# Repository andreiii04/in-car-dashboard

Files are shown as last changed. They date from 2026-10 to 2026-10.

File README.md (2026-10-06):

# In-Car Dashboard

A standalone telemetry display for a car: a custom 4-layer STM32 board with a 2.8" TFT, a 6-axis IMU, an environmental sensor and a GPS module. It powers from the car's 12 V socket through an ordinary USB-C car charger, starts a fresh session on every power-on with no buttons, shows live driving numbers, and writes a summary of each drive to an SD card.

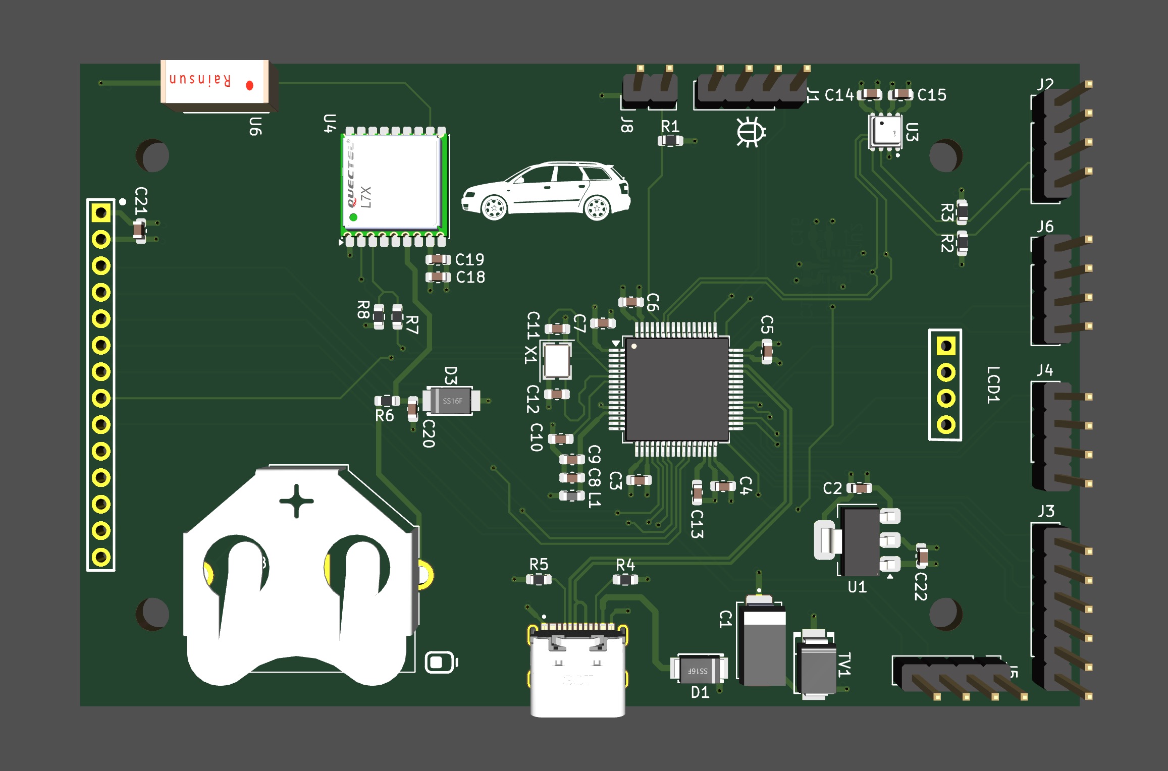
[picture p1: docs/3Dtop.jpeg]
Board, 3D view from the top


## What it shows and records

**Live, on the screen**
- A G-meter: a dot for the acceleration you feel, its magnitude, and the session's hardest braking, acceleration and cornering each way around the ring
- Speed, session maximum and distance (GPS)
- Temperature, humidity, pressure and gas resistance (BME680)
- Local time, time since power-up, satellites, position and altitude (GPS fused with the barometer)

**Per drive, on the SD card** — one file, `SESSIONS.JSON`, a single valid JSON document with one fixed-size block per drive:
- Start time (UTC and local), duration, moving time, distance, top speed
- Hardest acceleration, braking and cornering, worst lateral load against the car's rollover limit
- Peak pitch and roll and how close they came to the car's limits
- Temperature, pressure and humidity min/max/average; climb and descent
- A `faults` section with every init result and error counter, so a drive that went wrong says so in its own record

The record is rewritten in place every 10 s, because the car cuts power without warning. A cut can only ever damage the current drive's block, and the two writes that move the closing bracket are ordered so an interrupted one repairs itself on the next boot.

## Hardware

| Part | Role | Interface |
|---|---|---|
| STMicroelectronics STM32F446RCT6 | Cortex-M4F MCU, 180 MHz, 256 KB flash, 128 KB RAM | — |
| STMicroelectronics LSM6DSOTR | 6-axis accelerometer + gyroscope | I2C1, data-ready on INT1 |
| Bosch Sensortec BME680 | Temperature, pressure, humidity, gas | I2C1 |
| Quectel L76L-M33 | GPS + GLONASS receiver, 1 Hz NMEA | USART1, 9600 baud |
| GPS ANT-1 chip antenna | Passive GNSS antenna | RF_IN |
| KMRTM28028-SPI / MSP2807 | 2.8" 320×240 TFT, ILI9341 driver, full-size SD socket | SPI1 (display), SPI2 (SD) |
| Microchip MCP1825ST-3302E | 3.3 V LDO | — |
| GCT USB4930-00-A | USB-C: power, and a USB CDC debug console | USB OTG FS |
| Keystone 3003 | Coin-cell holder for the GPS backup supply | V_BCKP |

Protection on the 5 V input: a series Schottky against reverse polarity, a TVS diode and a 220 µF tantalum bulk capacitor. Five expansion headers (I2C, SPI3/I2S3, USART6, CAN1, two 32-bit timer channels) carry the protected 5 V rail for future add-on boards. Flashing and debugging go through a 4-pin SWD header with an ST-Link.

- **PCB:** 4-layer FR4, 1.6 mm, ENIG (two LGA sensors), 61.6 × 95.79 mm. Solid ground on In1, 3.3 V pour on In2. Made at JLCPCB.
- **Schematic:** three sheets, pictured below, or open the KiCad project.
- **Parts list:** [`docs/bom.csv`](docs/bom.csv), with manufacturer part numbers.

<p>
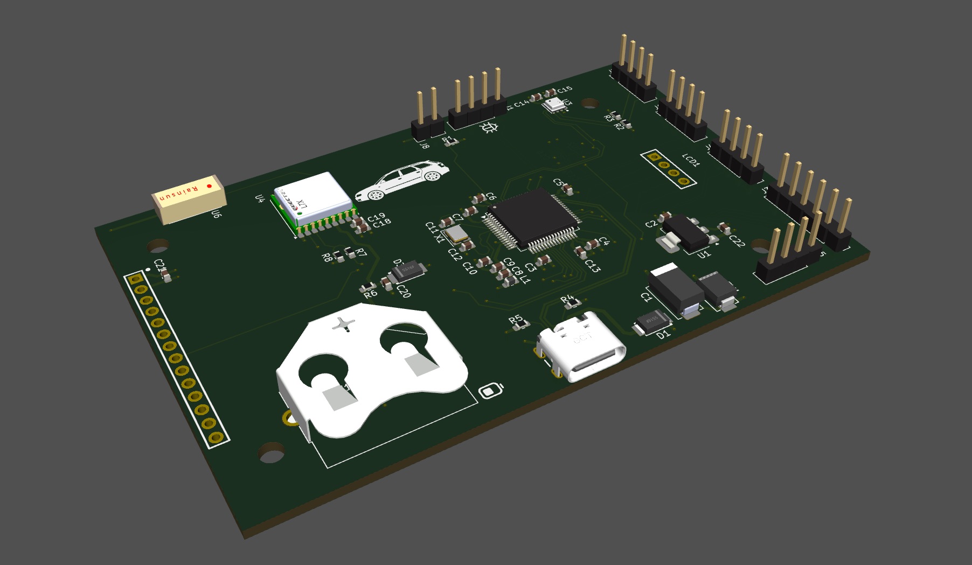
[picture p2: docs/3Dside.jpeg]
Board, side view
  
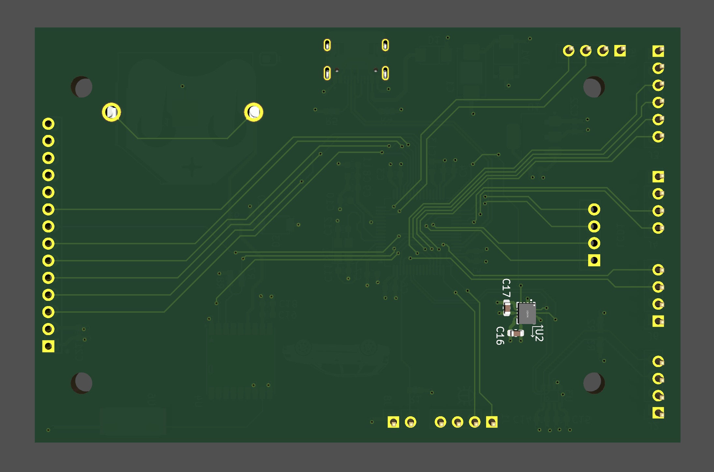
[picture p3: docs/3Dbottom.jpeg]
Board, bottom view, with the IMU on the underside
  
</p>

**Display mounting.** The display module is not soldered to the board and does not appear in the renders: female 2.54 mm sockets are soldered into all 18 LCD1 positions (the 14-pin display and touch row and the 4-pin SD row), and male headers on the module's own PCB plug into them, so the screen stacks face-up on top of the main board and can be lifted off. The board's four M3 holes match the module's 44 × 76.08 mm hole pattern, for standoffs between the two.

### Case

A 3D-printed bottom tray holds the board by its walls, with the USB-C opening on one side, intake vents at the BME680 end and exhaust vents at the far end. Source: [`hardware/case/bottom_tray.FCStd`](hardware/case/bottom_tray.FCStd) (FreeCAD 1.1), described in [`docs/dash_case.md`](docs/dash_case.md). The top case with the display bezel and SD slot is not designed yet.

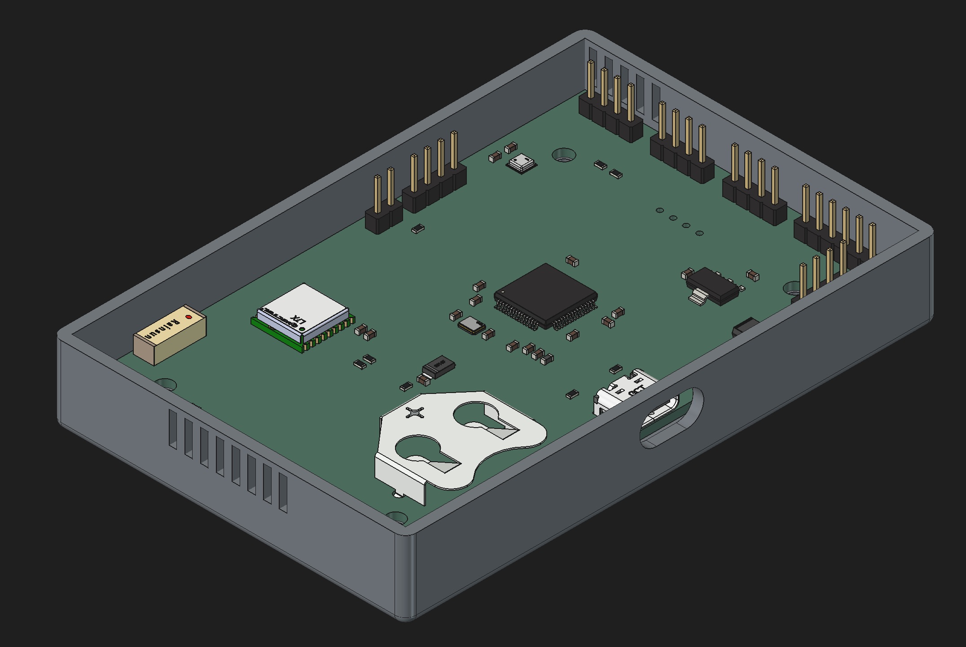
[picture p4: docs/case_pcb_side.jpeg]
Board in the bottom tray


### Schematic and layout

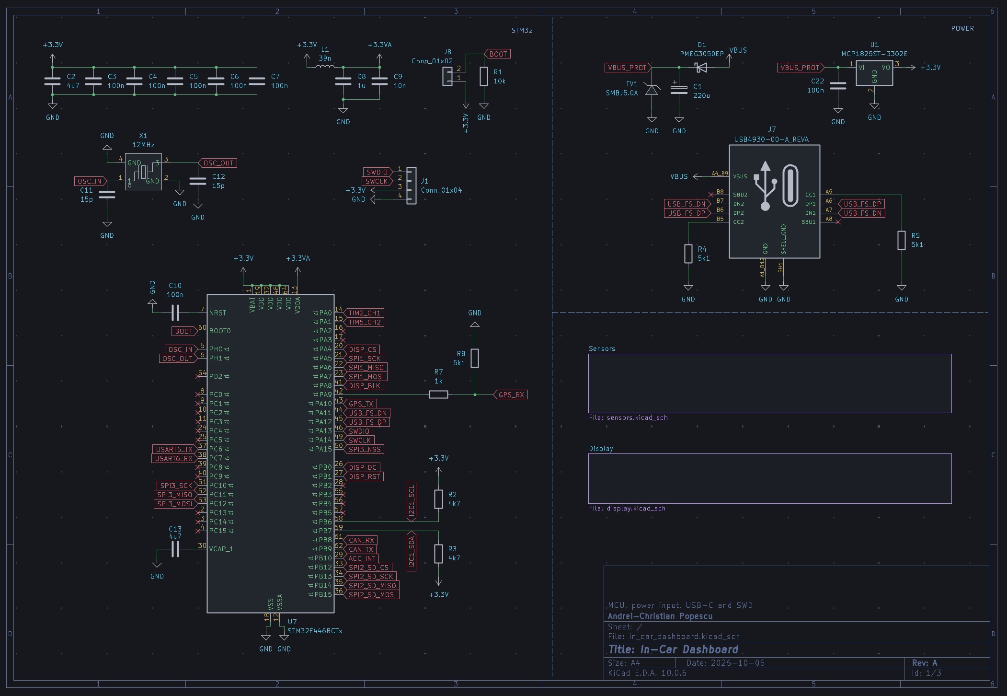
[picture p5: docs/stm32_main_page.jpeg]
Schematic sheet 1: MCU, power input, USB-C and SWD


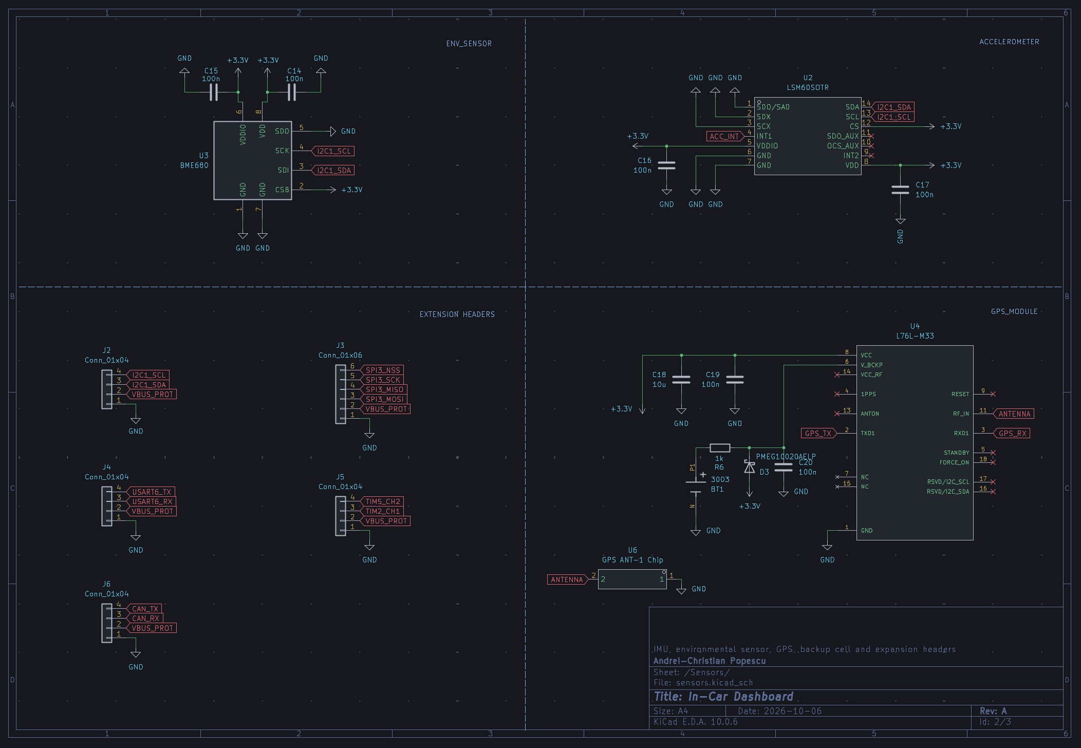
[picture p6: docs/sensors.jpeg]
Schematic sheet 2: IMU, environmental sensor, GPS, backup cell and expansion headers


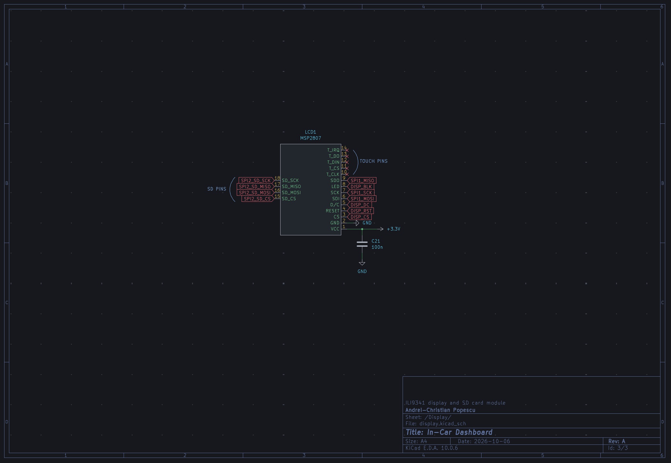
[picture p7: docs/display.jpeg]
Schematic sheet 3: display and SD card module


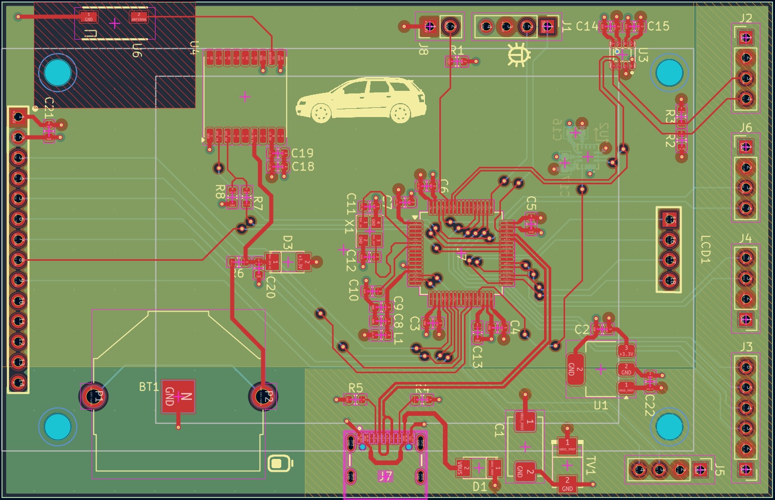
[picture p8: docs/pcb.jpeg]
PCB layout, top view


### Known issues on this revision

- **No copper keepout under the GPS antenna.** The antenna's datasheet asks for a copper-free corner on all layers; it was missed. With solid copper underneath, the module heard nothing, so the chip antenna is lifted about 1 cm above its pads on two wire stubs; it fixes with 9–16 satellites that way. A rev B would add the keepout or a U.FL connector for a patch antenna.
- **The display module never drives its SDO line,** so register reads return `0xFF`. The firmware treats the ID check as advisory; writes work normally.
- **The IMU sits on the underside of the board,** so the firmware's axis map flips two axes. This is by design, but it surprises anyone reading raw values.

## Firmware

C, bare-metal superloop on STM32 HAL (CubeMX-generated init), built with CMake and arm-none-eabi-gcc. No RTOS yet.

The loop is paced by the IMU's own data-ready interrupt at about 105 Hz. Each sample is mapped from sensor axes to vehicle axes (ISO 8855: X forward, Y left, Z up), run through the attitude filter, then handed to the trip statistics. Around that, on every pass:
- the GPS ring buffer is drained and NMEA sentences parsed
- the BME680 is triggered and read back in two halves every 3 s, so nothing blocks
- the screen redraws at 20 Hz, one 16-line band per pass, with no framebuffer
- the session record is rewritten every 10 s

| Stack | Modules |
|---|---|
| Sensors | `i2c_bus` → vendor drivers (ST `lsm6dso`, Bosch `BME68x`) → platform glue → `imu`, `env` |
| GPS | `uart_bus` (interrupt-driven ring buffer) → `nmea` (parser) → `gps` |
| Fusion and statistics | `attitude` (complementary filter, full Euler kinematics, mount rotation), `trip` (distance, peaks, lean, rollover margins, GPS-dropout coasting), `elevation` (GPS altitude fused with barometric pressure) |
| Display | `lcd` (ILI9341 over SPI) → `gfx` (band renderer, dirty rectangles) → `screen` |
| Storage | `sd_spi` (SD SPI mode, CRC on every command and block) → FatFs → `session_record` → `session_log` |
| Console | `usb_serial` (printf over USB CDC) → `console` |

Everything with no hardware in it is host-testable and tested on a PC, 243 checks across seven modules: `nmea`, `attitude`, `trip`, `elevation`, `gfx`, `sd_crc`, `session_record`. Expected values come from independent derivations rather than restatements of the code under test. Car- and mount-specific constants (axis map, calibration, wheelbase, track, centre-of-gravity height) live in one header, `firmware/App/Inc/vehicle_axes.h`, explained in [`docs/vehicle_info.md`](docs/vehicle_info.md).

Some decisions worth knowing before changing anything:
- **Pitch and roll come from accelerometer and gyroscope fused.** The car's own acceleration is subtracted first, using GPS speed and speed × yaw rate, so braking and cornering don't read as tilt.
- **GPS speed below 10 km/h is treated as standing still.** A poor fix wanders by several km/h at rest, so the floor is applied once, where the fix enters the trip statistics.
- **Climb and descent come from the barometer alone.** The GPS height after a cold start drifts by up to hundreds of metres over minutes, and counting that as climb was a real bug.
- **The mount is calibrated in the car,** with the board's rest reading measured in both directions on the same spot and averaged, so a sloping parking space cancels out.

The reasoning behind these and most other choices, written down while I learned embedded from scratch, is in [`docs/notes.md`](docs/notes.md); code comments that say "see docs/notes.md" point there.

## Repository layout

```
firmware/            STM32 firmware (CMake, CubeMX project dashboard_firmware.ioc)
  App/               hand-written code: Inc/, Src/, Drivers/ (vendor), Fonts/ (generated)
  Core/ Drivers/ FATFS/ Middlewares/ USB_DEVICE/   CubeMX- and ST-generated
  tests/             host tests, each file carries its own compile line
  tools/             font generator
hardware/
  pcb/               KiCad 10 project in_car_dashboard
  libraries/         custom symbols, footprints and 3D models used by the board
  case/              FreeCAD source of the case tray
docs/                case design note, the car's numbers and what each one is used for, my notes
                     from building it, schematic and board pictures, renders, BOM
```

## Building and flashing

Requirements: CMake ≥ 3.22, Ninja, and `arm-none-eabi-gcc` on the `PATH` (STM32CubeCLT provides all three).

```sh
cd firmware
cmake --preset Debug
cmake --build build/Debug
```

The output is `build/Debug/dashboard_firmware.elf`. Flash it over SWD with an ST-Link: from an IDE (CLion with the STM32 plugin, or STM32CubeIDE), or with STM32CubeProgrammer. The serial console is the USB-C port itself, at `/dev/cu.usbmodem*` on macOS; the baud rate is ignored.

Host tests build with any C11 compiler. For example:

```sh
cd firmware
cc -std=c11 -Wall -Wextra -I App/Inc tests/test_trip.c App/Src/trip.c -lm -o /tmp/test_trip && /tmp/test_trip
```

Each file in `tests/` has its own line in its header.

## Opening the hardware

- **PCB:** open `hardware/pcb/in_car_dashboard.kicad_pro` in KiCad 10. The project's symbol and footprint paths are relative to the project, so the custom parts in `hardware/libraries/` resolve on any machine; everything else comes from KiCad's standard libraries. The 3D models of the custom parts are not included, since they come from third parties: the board opens, checks and exports normally, and those parts just show without a body in the 3D viewer. To get them back, download the STEP models from the manufacturers and put each in `hardware/libraries/<library>/<library>.3dshapes/` under the file name its footprint asks for.
- **Case:** open `hardware/case/bottom_tray.FCStd` in FreeCAD 1.1. It was printed in one piece, floor down, no supports.

## Datasheets

Not included in the repository; all are available from the manufacturers:
- STM32F446RC (STMicroelectronics)
- LSM6DSO (STMicroelectronics)
- BME680 (Bosch Sensortec)
- L76L-M33 datasheet and its GNSS protocol specification (Quectel)
- ILI9341 (Ilitek)
- MSP2807 / KMRTM28028-SPI module drawing
- MCP1825 (Microchip)
- USB4930 / USB4940 (GCT)
- 3003 coin-cell holder (Keystone)
- PMEG10020AELP and PMEG3050EP Schottky diodes (Nexperia)
- SMBJ5.0A TVS diode (SMBJ series)
- GPS ANT-1 chip antenna
- SD Physical Layer Simplified Specification v2.00 (SD Association)

## Status

Working on the bench and in the car. Bring-up is complete: console, sensors, calibration, GPS, attitude, interrupt-paced sampling, display, SD logging and the main loop. The first long drive, 118.5 km, matched the route distance and ran with every fault counter at zero.

Still to do:
- Air-quality index through Bosch's BSEC library, which is closed source and won't be in this repository
- Tuning the filters against logged drives, and a faster GPS rate
- The top case
- A second screen for pitch and roll off-road

## License

The hardware design, case, firmware and documentation in this repository are released under the [MIT License](LICENSE).

The custom symbols and footprints in `hardware/libraries/` were drawn from, or adapted from, manufacturer and EasyEDA / SnapEDA sources; their 3D models are not redistributed here.

Third-party code keeps its own licence:
- **CMSIS:** Apache 2.0, see `firmware/Drivers/CMSIS/LICENSE.txt`
- **STM32F4 HAL:** BSD-3-Clause, see `firmware/Drivers/STM32F4xx_HAL_Driver/LICENSE.txt`
- **STM32 USB Device Library:** ST SLA0044, see `firmware/Middlewares/ST/STM32_USB_Device_Library/LICENSE.txt`
- **FatFs R0.12c:** ChaN's FatFs licence, in its source header
- **Bosch BME68x SensorAPI:** BSD-3-Clause
- **ST LSM6DSO driver:** BSD-3-Clause, from ST's `lsm6dso-pid` repository

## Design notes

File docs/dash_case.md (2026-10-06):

# Car Dashboard — Bottom Case Tray (FreeCAD 1.1.3, macOS)

Status: **bottom tray printed and test-fitted (Oct 2026).** The board drops
in and is held snugly by the walls alone, sits flat, and the USB-C cable seats.
Not yet screwed down; on the car's dash since 4 Oct 2026, front edge forward,
~43° nose up. Final object: `Fillet001`. Next up: standoffs, then design the
top case.

**Files** (in `hardware/case/`): `bottom_tray.FCStd` is the FreeCAD source;
`bottom_tray.3mf` and `bottom_tray.stl` are the meshes exported from it per
section 8. Inside the FreeCAD file the imported board is still called
`IN_CAR_DASHBOARD 1` — the KiCad project's old name.

---

## 1. Context

Enclosure for the STM32F446RCT6 in-car telemetry dashboard PCB. This note
covers the **bottom tray only** — the part the PCB bolts into. The top case
(display bezel + SD-card access) comes later.

Everything is modelled in the **Part** workbench with primitives and booleans
— no Sketcher, no constraints. Every feature is a Cube or Cylinder with typed
Placement values. The geometry is all rectangular/cylindrical, so this keeps
every dimension explicit and easy to trace back to a number in this file.

---

## 2. Coordinate system

The KiCad STEP export (`IN_CAR_DASHBOARD 1`) is placed so the board's
bottom-left corner sits on the origin. **All case geometry is dimensioned in
the PCB's own frame — never move the STEP.**

| Reference | Value |
|---|---|
| Board outline | 61.60 (X) × 95.80 (Y) |
| Board occupies | X: 0 → +61.60, Y: 0 → −95.80 |
| Board bottom face | z = 0 |
| Board top face | z = +1.52 |
| Deepest bottom-side protrusion | z = −1.00 (clipped THT pin tips) |

Wall naming used below: **X = 0 / X = 61.6** are the long walls, **Y = 0**
(BME680 end) and **Y = −95.8** (coin-cell end) are the short walls.

The Top view renders rotated 90° (+X up-screen, +Y left), so the board looks
landscape even though it's portrait.

---

## 3. Vertical stack

All z values are in the PCB frame, so board thickness is already included.

| Feature | z |
|---|---|
| Floor underside | −6.00 |
| Cavity floor / boss base | −4.00 |
| Boss top / board underside | 0.00 |
| Board top face | +1.52 |
| Wall top | **+9.00** (7.48 above the board top) |
| Display PCB underside (10 mm standoff) | ≈ +11.52 |

- Floor 2.0 mm, walls 2.0 mm, inside wall height 13.0 mm
- Bosses 4.0 mm tall → 3.0 mm clearance under the clipped pin tips
- 2.5 mm gap between the wall top and the display PCB
- External envelope: **67.60 × 101.80 × 15.00 mm**
- Edges broken for handling: 2.0 mm fillet on the 4 vertical corners, 0.8 mm
  on the 4 bottom edges. Top edges left sharp — the top case mates there.

---

## 4. Mounting

Ø3.20 PCB holes (M3 clearance). The pattern matches the MSP2807 display
exactly: **44.00 × 76.08**, X-centred at (61.6 − 44)/2 = 8.80.

| | X | Y |
|---|---|---|
| H1 | 8.80 | −12.80 |
| H2 | 52.80 | −12.80 |
| H3 | 8.80 | −88.88 |
| H4 | 52.80 | −88.88 |

Y values were probed directly off the STEP (hole edges at 12 and 6 o'clock,
averaged) and cross-checked against the datasheet's 76.08 span and 6.92
bottom offset.

Bosses are Ø6.5, with a Ø2.5 pilot through boss + floor. That gives 6 mm of
thread engagement for the standoff stud.

**Fastening stack:**
- **Board → tray:** M3 male–female hex standoff. The 6 mm male stud
  thread-forms into the boss pilot and the standoff shoulder clamps the board.
- **Display → standoff:** M3×6 pan head from above, into the standoff's
  female end.
- Standoff body ~10 mm (10+6 variant); still to be confirmed against the
  MSP2807's back-side clearance.
- Hand-tighten only. Thread-formed plastic tolerates about 3–4 insertion
  cycles.

---

## 5. USB-C cutout

**Connector:** GCT USB4930-00-A (the STEP model is `usb4930_00_a`). The
supplier's drawing link points to the USB4940 — the measured model height
matches the USB4940 drawing.

- Mouth flush with the board edge at X = 61.6
- Centre measured at **Y = −48.10, z = 3.25**
- Shell top at z ≈ 4.9

**Why the hole is stepped.** The mouth sits 3.0 mm behind the outer wall face
(1 mm gap + 2 mm wall). The datasheet only guarantees ≥ 1.85 mm between the
receptacle face and the plug body when fully mated, so the cable's
plug body (the moulded part) has to enter the wall by ~1.2 mm. A hole sized
for the receptacle alone would stop the plug short of full insertion. A
pure funnel fails the same way — it narrows faster than the plug body needs.

The solution is a counterbore for the plug body, a smaller through-hole for
the metal plug, and a small lead-in chamfer between them. All three are
stadium shapes (straight sides, round ends), concentric on the receptacle.

| Feature | Size | X range | z range |
|---|---|---|---|
| Pocket (plug body) | 12.50 × 6.75, r 3.375 | 63.2 → 64.6 (1.4 deep) | −0.125 → 6.625 |
| Through-hole (metal plug) | 9.80 × 4.00, r 2.0 | 62.6 → 63.2 | 1.25 → 5.25 |
| Lead-in chamfer | 0.5 mm equal distance | through-hole rim at X = 63.2 | — |

- 2.375 mm of wall above the pocket, 3.75 mm above the through-hole
- 0.6 mm web between the pocket floor and the inner wall face
- The pocket is sized tight for a slim plug body. The USB-C spec maximum is
  12.35 × 6.5, so bulky plugs may not fit; if one is tight, grow the pocket
  radius by +0.15 mm.

---

## 6. Ventilation

The BME680 sits at **(6.55, −18.65)** on the top side, close to the Y = 0 /
X = 0 corner. Vents are placed so fresh air reaches the sensor first and
leaves at the far end, away from the MCU and regulator heat.

All slots are **1.5 wide × 6.0 tall**, through the 2 mm wall, **z 2.0 → 8.0**
(1.0 mm of wall left above them), with a **3.0 mm pitch**.

| Wall | Role | Slots | Slot X centres |
|---|---|---|---|
| Y = 0 (BME end) | inlet | 5 | 0.55 / 3.55 / **6.55** / 9.55 / 12.55 — centred on the BME680 |
| Y = −95.8 (far end) | exhaust | 8 | 20.3 → 41.3 — centred on the board (30.8) |

I didn't put vents on the long X = 0 wall, to keep dust down. The Y = 0 end
will face the car's climate vents. Keep in mind that a direct air jet on the
inlet will bias the BME680 toward vent-air temperature and humidity rather
than cabin air.

---

## 7. Feature tree

```
Fillet001                       ← FINAL — 0.8 mm on the 4 bottom edges
└─ Fillet                       ← 2.0 mm on the 4 vertical corners
   └─ Chamfer                   ← 0.5 mm lead-in on USB through-hole
      └─ Cut002  (Refine = true)      ← tray minus all cutouts
         ├─ Cut001                 ← base tray with boss pilots
         │  ├─ Fusion               ← shell + bosses
         │  │  ├─ Cut
         │  │  │  ├─ Cube           outer   67.6 × 101.8 × 15.0  @ (−3, −98.8, −6)
         │  │  │  └─ Cube001        cavity  63.6 × 97.8  × 13.5  @ (−1, −96.8, −4)
         │  │  └─ Cylinder…003      bosses  r 3.25, h 4   @ holes, z −4
         │  └─ Fusion001            pilots  r 1.25, h 9   @ holes, z −7
         └─ Fusion002               ← all cutting tools
            ├─ Cube002              pocket middle   2 × 5.75 × 6.75   @ (63.2, −50.975, −0.125)
            ├─ Cylinder008/009      pocket ends     r 3.375, h 2      @ y −50.975 / −45.225, z 3.25
            ├─ Cube003              through middle  1.9 × 5.8 × 4     @ (62.1, −51.0, 1.25)
            ├─ Cylinder010/011      through ends    r 2.0, h 1.9      @ y −51.0 / −45.2, z 3.25
            ├─ Cube004…008          vent A  1.5 × 3 × 6  @ x −0.2…11.8,  y 0.5,   z 2
            └─ Cube009…016          vent C  1.5 × 3 × 6  @ x 19.55…40.55, y −99.3, z 2
```

The vertical corners and the bottom edges ended up as two separate Fillet
operations rather than one, because pressing Enter in the radius box closes
the dialog instead of just committing the value. Same result, one extra node.

USB cylinders are rotated Axis (0, 1, 0), Angle 90°, so they run along +X.

**Modelling rules I stuck to:**
- Every cutting tool overshoots the faces it cuts. Coplanar faces break
  booleans — that's also why the cavity cube pokes 0.5 mm above the wall top.
- The chamfer and the two fillets are the **last** operations, in that order.
  They're bound to edge IDs (the chamfer to Edge193/196/199/202 of `Cut002`),
  so any upstream change can renumber them and break the chain. If that
  happens, delete them and redo only those three steps.
- Bottom fillets stay small. A fillet on a bottom edge is a real overhang
  against the build plate, so anything much past 0.8 mm droops on the first
  layers. The vertical corner fillets cost nothing — that surface stays
  vertical all the way up.

---

## 8. Printing

**Export:**
1. `Fillet001` → Part → Check Geometry. Must report no errors.
2. Hide `IN_CAR_DASHBOARD 1` (select, Space).
3. Mesh Design workbench → select `Fillet001` → Meshes → Create mesh from
   shape → **Standard**, surface deviation `0.01 mm`, angular deviation `5°`.
   The fine deviation matters: the USB hole ends and the corner fillets come
   out visibly faceted at the default.
4. Select the **mesh** object → File → Export → **3MF** (preferred) or STL.
5. Also export `Fillet001` itself as **STEP** from the Part workbench, as the
   editable version to hand over alongside the mesh.

3MF stores units explicitly; STL is unitless and is occasionally read as
inches, so say "mm" when handing it over.

**Print setup:**
- Orientation: floor on the bed, walls up
- No supports — the slot tops and USB openings are short bridges (≤ 5.8 mm),
  and the round ends are self-supporting
- 0.4 nozzle, 0.2 mm layers
- ≥ 4 perimeters and ≥ 30 % infill, so the bosses are close to solid
  around the pilot holes (the standoffs thread-form into them)
- Material: PLA is fine for the fit test. For the car, use **PETG or ASA** —
  PLA starts softening around 55–60 °C, which a parked car easily exceeds.

**After the first print, check:**
- [x] USB-C cable seats fully
- [ ] Standoffs thread in without cracking the bosses — no screws fitted yet
- [x] Board sits flat with the USB mouth centred in the hole — the fit is
  tight enough to hold the board without screws, and the tray sits flat on
  the table

**First fit result (3 Oct 2026):** the board was re-calibrated in the tray, on
the same table as the original bench calibration, and those values are now the
"flat" set in `vehicle_axes.h`. The bench values were off by pitch +0.9° /
roll −1.3° because the bare board had rested on its THT solder tails, not on
its mounting holes; the tray is the better flat reference. Since 4 Oct the
tray sits on the dash and the active set is the car calibration (43.4° nose
up, 2.5° roll), described in [`vehicle_info.md`](vehicle_info.md).

---

## 9. Open items

- **Top case:** needs a cutout at the board edge for the **full-size SD card**
  (measured ~9.5 mm above the board top including board thickness), so the
  card stays removable without opening the case. It mates on the wall top at
  z = 9.0.
- **Standoff length:** confirm the 10 mm body against the MSP2807's back-side
  components before ordering.
- **Boss heights:** confirm all four read `Height = 4`, `z = −4`. Earlier, one
  looked prouder in an isometric view. Still unchecked: a proud boss tilts the
  board, and the in-tray calibration would bake that tilt in as "flat", so it
  cannot reveal one. Measure the heights once the standoffs clamp the board.

---

## 10. Reference files

- MSP2807 mechanical drawing — display PCB 50 × 86, hole pattern 44 × 76.08,
  4 × Ø3.20
- GCT USB4930 specification and USB4940 drawing — receptacle and mating depth
- BME680 datasheet — sensor position and venting

The datasheets are not in the repository; the README lists them. The board
itself is `hardware/pcb/in_car_dashboard.kicad_pcb` (KiCad STEP export).

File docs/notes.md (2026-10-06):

# notes

my own notes while learning this. plain language on purpose, i rewrite bits as i
understand them better.

two words that come up a lot:

  step      the bring-up order i followed, one piece of the board at a time
              0  usb console         5  loop paced by the IMU's data-ready line
              1  i2c sensors         6  display
              2  bench calibration   7  sd card
              3  gps                 8  the main loop
              4  pitch and roll      9  BSEC, 10 tuning - not done yet
  session   one power-on, one record in SESSIONS.JSON on the card
              5      19 sep         first drive, 18 min
              6-8    28 sep-3 oct   back on the bench with the fixes from 5
              17     3 oct          first long drive, 2 h 19 min, 118.5 km

## the layers

the code is stacked - each layer only talks to the one under it. the file list
and what each layer does is in the README; what matters here is why.

swap the IMU for a different chip and only imu.c and its glue file change,
everything above keeps working. it also keeps each file small enough to read in
one go.

three files sit above all of it and are stacked on nothing - attitude.c, trip.c
and elevation.c get handed plain numbers by main. nothing hardware-shaped goes
in, so all three run on the mac.

the usb console is the one stack that is mostly ST's:

  usb_serial.c             my module - printf lands here
  usbd_cdc_if.c            ST's "serial port" class
  usbd_core.c              ST's core - runs the usb interview
  usbd_conf.c              ST's glue down to the HAL
  HAL                      the usb hardware on PA11 and PA12

vendor drivers i re-download rather than patch by hand - the next download would
wipe the patch and i would not notice.

## what a driver actually is

a chip like the LSM6DSO is a box of numbered mailboxes called registers, one
byte each. write to 0x10 and the sample rate changes; read 0x28 to 0x2D and you
get the accelerometer. that is the whole interface.

a driver is code that knows which mailbox is which, so i don't memorise 100
numbers. instead of "put 0x40 into register 0x10" i write

  lsm6dso_xl_data_rate_set(..., LSM6DSO_XL_ODR_104Hz)

ST and Bosch publish these free, written to work on any microcontroller. which
is why the glue file exists.

## why the glue file exists

ST's driver has no idea what an STM32 is. it asks me for two functions instead -
one that reads bytes, one that writes them - and calls those when it needs the
bus.

handing over a function like that is a function pointer: a variable holding
where a function lives instead of a number.

so lsm6dso_platform.c has two small functions in the shape ST asked for, each
calling my i2c_bus_read_reg / i2c_bus_write_reg, bundled into a struct:

  stmdev_ctx_t lsm6dso_ctx = {
      .write_reg = lsm6dso_platform_write,
      .read_reg  = lsm6dso_platform_read,
      .mdelay    = lsm6dso_platform_delay,
      .handle    = &lsm6dso_i2c_addr,
  };

that struct is the context, and every ST call takes it first.

.handle is a spare pointer ST hands back untouched. i point it at the device
address, because my i2c_bus functions need to know which chip to talk to and
ST's driver has no other way of telling me. Bosch does the same and calls it
intf_ptr.

## I2C, enough to follow the code

two wires shared by every chip - SDA is data, SCL is clock. each chip has an
address so they don't talk over each other. BME680 is 0x76, LSM6DSO is 0x6A.

addresses are 7 bits. the HAL wants them shifted left by one because it uses the
freed bottom bit for read vs write. my wrapper does the shift inside, so i
always pass the plain datasheet number.

a normal read is "hey 0x6A, i want register 0x28" then "give me 6 bytes".
HAL_I2C_Mem_Read does that whole exchange in one call, which is why i used it
instead of building the sequence myself.

## what an IMU is

inertial measurement unit. one package holding:

  accelerometer   how hard it is being pushed
  gyroscope       how fast it is being turned

3 axes each, 6 numbers - hence 6-axis.

i named my module imu_ and not lsm6dso_ because ST's driver owns that prefix.
lsm6dso_status_t already exists in their header, so reusing it would not compile.
imu also names the job instead of the part.

## accelerometer numbers

measured in g, one g being earth's gravity.

the confusing bit: sitting still on a table it does not read zero. it reads 1 g
on whichever axis points up, because gravity is always being measured. that is
what makes tilt possible.

rough car numbers:

  sitting still            1 g on the vertical axis
  hard braking             about 1 g forwards
  emergency stop           up to 1.2 g
  normal cornering         0.3 to 0.8 g sideways
  pothole                  2 to 3 g extra straight up, very briefly

## gyroscope numbers

dps, degrees per second.

  90 dps    quarter turn every second
  360 dps   full spin every second

a bend at 50 km/h on a 30 m radius is about 26 dps. a tight hairpin taken slowly
is about 48 dps. normal driving basically never passes 60 dps.

## ODR - output data rate

how many measurements a second. 104 Hz = 104 samples a second, like frames per
second on a camera pointed at the car's movement.

why not pick a low number and save effort - aliasing. same effect as wagon wheels
in old films looking like they spin backwards: the camera samples too slowly, so
a fast motion gets recorded as a slow wrong one.

a car is full of fast vibration - engine, road, tyres. sample too slowly and that
vibration is not missed, it is recorded as slow fake movement that looks exactly
like braking. once it is in the data it cannot be removed.

how i got to 104 Hz:

  1. real car body movement is under about 15 Hz
  2. bare minimum is twice that, so over 30 Hz
  3. in practice 5-10x not 2x, so over 75 Hz
  4. the chip offers 12.5, 26, 52, 104, 208, 417, 833
  5. 104 is the first above 75

why not 208 - the built-in smoothing filter is tied to the ODR. at 104 it cuts
above 33 Hz, exactly what i want. at 208 it only cuts above 67, so more vibration
gets through. higher is worse here.

## full scale - the measuring range

the biggest value before it maxes out. like a bathroom scale: one that goes to
200 kg weighs more but each step it can tell apart is bigger. bigger range = less
detail per step. the smallest step is an LSB, one count of the raw number.

accel:

  ±2 g     0.061 mg
  ±4 g     0.122 mg
  ±8 g     0.244 mg
  ±16 g    0.488 mg

i took ±4 g. the range is per axis, not total, and the worst case is vertical -
1 g just sitting there plus 2-3 g on a pothole, which maxes ±2 g straight away.

the lost detail does not matter: the sensor's own zero error is up to ±20 mg,
164x bigger than the 0.122 mg step. step size is not what limits accuracy, the
zero error is. so ±4 g is basically free.

gyro:

  ±125 dps    4.375 mdps
  ±250 dps    8.75 mdps
  ±500 dps    17.50 mdps
  ±1000 dps   35 mdps
  ±2000 dps   70 mdps

±500 dps for the same reason. driving stays under 60 dps so ±250 would do, but
the zero error is ±1 dps = 1000 mdps, 28-57x bigger than either step. so i take
the wider range free and get headroom if the car ever slides.

## what each step of imu_init does

in order, and the order matters:

  1. WHO_AM_I - one register that always holds 0x6C. if that works, the bus, the
     address and the part are all confirmed at once. if it fails nothing else is
     worth trying.

  2. software reset - back to factory defaults, so a restart behaves like a real
     power cycle. the reset bit clears itself, so the code loops until it does,
     with a timeout so a dead sensor cannot hang the program.

  3. disable I3C - a newer protocol on the same pins. not used, and left on a
     glitch can knock the chip off the bus until it is power cycled.

  4. block data update - each reading is 2 bytes read one at a time. without this
     a new sample can land between the two and i get half of one reading glued to
     half of another. shows up as rare impossible spikes.

  5. auto increment - read 6 bytes in one go instead of asking for each register.

  6. full scale - the range for accel and gyro.

  7. ODR last - writing the sample rate is what wakes the sensor and starts it
     measuring, so everything else is already set by the first sample.

## what the BME680 measures

second sensor on the same bus:

  temperature      degrees C
  pressure         Pascal from the driver, i turn it into hPa
  humidity         % relative humidity
  gas resistance   ohms - not air quality yet, see below

env.c wraps it like imu.c wraps the LSM6DSO. called env for the role, not the
part.

## sleep and forced mode

only two modes:

  sleep    does nothing, almost no power, boots into this
  forced   one full measurement, then back to sleep on its own

there is no keep-measuring-forever mode on this chip. the BME688 has one called
parallel mode, and since Bosch ships one driver for both parts the constant
BME68X_PARALLEL_MODE sits in the header - it just does not work on a BME680.

so a read is three steps: trigger, wait, read out. that is the big difference
from the IMU, which free-runs at 104 Hz and lets me grab whatever is in its
registers whenever.

i do not guess the wait - bme68x_get_meas_dur() works it out from the current
settings. with mine that is about 43 ms plus 100 ms of heater, so env_read blocks
for roughly 143 ms.

## oversampling

the sensor takes several readings internally and averages them. averaging N cuts
random noise by sqrt(N), and costs time and power roughly in line with N.

different value for each of the three, because each runs out of usefulness for a
different reason.

temperature 2x. the part is only accurate to ±0.5 C and that is a calibration
limit, averaging cannot fix it - its noise is already 0.005 C at the lowest
setting, 100x smaller. i still do not skip it, because its value is used to
correct pressure and humidity.

pressure 16x. the one place the electronics really are the limit. at 16x the
noise is 0.12 Pa, about 1.7 cm of altitude. normally 16x gets avoided for being
slow, but i only measure every 3 seconds.

humidity 1x. accurate to ±3 % at best, and the sensing material needs 8 seconds
to react to 63% of a change. that limit is physical. averaging cannot speed up a
slow part.

## the IIR filter

smoothing inside the sensor, a running average:

  new = (old * (c - 1) + fresh reading) / c

bigger c is smoother but slower. temperature and pressure only, not humidity or
gas.

the datasheet says it is for "slamming of a door or wind blowing into the
sensor", which is exactly a car - doors slam, vents blow across the dash, windows
open at speed. all real pressure spikes i do not want on the display.

coefficients are 0, 1, 3, 7, 15, 31, 63, 127. i picked 3. the catch is it counts
samples, not seconds, and i measure every 3 s:

  c = 3     ~3 samples      ~9 seconds
  c = 15    ~15 samples     ~45 seconds
  c = 127   ~127 samples    over 6 minutes

the log wants temperature range and pressure per drive, so a heavy filter would
smear out climbing a mountain road or entering a tunnel. 3 kills door slams and
keeps up with real change.

a desk decision off the datasheet, not measured. if pressure looks jumpy in the
car i try 7; if it visibly lags going uphill, drop to 1.

## the gas sensor

a tiny plate inside that gets heated, with a sensing layer on top. the resistance
of that layer changes with the gases touching it.

300 C for 100 ms, Bosch's own example values. the driver caps at 400 C and
4032 ms.

the reading comes with a validity flag. env_read checks two status bits - one
says the measurement finished, the other says the plate actually reached target.
if either is missing the ohms mean nothing.

that is why gas_valid sits in env_sample_t next to the value instead of env_read
returning an error: temperature, pressure and humidity are still fine in that
same reading, so there is no reason to throw them away.

gas_valid is false on the first readings after power-on - the plate needs a few
cycles. confirmed on the board.

the heater is also what makes this sensor draw real current. the microamp figures
in the datasheet are for temperature, pressure and humidity only.

## ohms are not air quality

the resistance on its own does not mean much. it moves with humidity, with
temperature, and with the age of the sensor. IAQ, eCO2 and VOC need BSEC, a
closed binary library from Bosch.

that is its own job, and a bigger one than i first thought:

- not in the repo. needs a licence click-through, and the right prebuilt version
  for this exact chip and compiler
- it takes over the sensor config. instead of me setting oversampling and heater
  once in env_init, BSEC says what to use before each measurement. so adding it
  rewrites env.c rather than adding to it
- it wants nanosecond timestamps as 64-bit. HAL_GetTick gives 32-bit ms, which
  wraps after 49 days
- it runs on a fixed schedule and remembers state between calls. that state takes
  days of runtime before its accuracy rating climbs from 0 to 3, so it has to be
  saved to the SD card and reloaded on the next boot. without that every drive
  starts from scratch and the number never becomes useful

the last two are why BSEC cannot happen before main() exists - it needs the task
loop and the card first.

## the GPS is a different kind of device

the two sensors sit silent until i read a register. the GPS just starts talking
once it has power and never stops - a burst of text every second, forever,
whether i am listening or not.

it sends text, not numbers:

  $GNRMC,080608.000,A,3029.461489,N,11430.072002,E,0.00,148.41,210423,,,D,V*09

so the work is string parsing, not register decoding.

and the UART hardware holds exactly one byte, so if i am busy when the next
arrives the old one is gone. hence an interrupt filling a buffer in the
background instead of reading when convenient.

## what a NMEA sentence looks like

  $        every sentence starts with this
  GN       talker ID, 2 letters, which constellations gave the fix
  RMC      sentence type, 3 letters
  ,...,    the fields, comma separated
  *09      star then a 2 digit checksum
  CR LF    end of line

the checksum is an XOR of every byte between the $ and the *. cheap, and worth
doing - a corrupted sentence with a believable speed in it would quietly poison
the trip stats.

fields are left completely empty when there is no value, so i get two commas next
to each other and every field has to be checked before use.

i parse two types:

  RMC   position, speed, course, UTC date and time
  GGA   fix quality, satellites used, altitude, HDOP

## the talker ID trap

the two letters after the $ change with which constellations produced the fix.
from the Quectel spec:

  GPS + Galileo                 GN
  GPS + GLONASS + Galileo       GN
  GPS + BDS                     GP
  no fix yet                    always GP

so before a fix i get $GPRMC and after a fix $GNRMC. matching the whole "$GPRMC"
would make the GPS look like it stopped working at exactly the moment it started
working. so i match only the last three letters and ignore the talker.

GGA is odd - its talker stays GP even in multi constellation mode.

## speed is in knots

the spec says knots, not km/h. 1 knot is 1.852 km/h. conversion needed in main().

## why double type for latitude and longitude

NMEA gives ddmm.mmmm - degrees and minutes glued together. on the L76-L the
minutes have 4 decimals, so the smallest step reported is 0.0001 minutes, about
18 cm on the ground.

a float holds about 7 significant digits. at 45 degrees that is roughly 0.6 m,
3x coarser than what the module actually gives. so float would throw away real
precision. double it is.

the M4 has a hardware FPU for float only. double still works, the compiler just
calls software routines, maybe 10-50x slower. fine for two numbers once a second.
the rule is no doubles in a fast loop - not the 104 Hz IMU path, not per pixel.

one trap: a plain 1000.0 in C is a double, so float / 1000.0 does slow software
maths. that is why my code says 1000.0f and 100.0f.

## the ring buffer

the interrupt fires once per byte and drops it into a 2048 byte circular buffer
(256 until oct - see back on the bench). the main loop takes bytes out later.

head is only written by the interrupt, tail only by the main loop. the two never
write the same variable, so no locking.

256 because at 9600 baud only ~96 bytes can arrive in 100 ms, so polling every
100 ms leaves room. if uart_bus_overruns() is ever not 0, i am not polling often
enough.

easy to miss: HAL UART stops receiving after a framing or noise error and never
restarts on its own. a car is full of electrical noise, so without
HAL_UART_ErrorCallback restarting it, one glitch kills the GPS until the next
power cycle.

## what the fix age really says

gps_fix_age_ms counts from the last RMC that parsed, whether it carried a
position or not. on purpose - the module keeps sending RMC once a second even
with no sky, the sentence just says V for void instead of A:

  fix_valid false, age small    module alive, no sky - a tunnel
  age large                     nothing arriving - module or wiring dead

one rule for wiring main() later: hand trip_update_gps a fix only when
updated_tick has changed. every call restarts its between-fixes clock, so
repeating the same fix grinds the forward acceleration estimate down to zero and
the compensation quietly switches itself off.

## this one can actually be tested

nmea.c has no HAL and no hardware - string in, numbers out. so it compiles on the
mac and i can feed it the example sentences from the Quectel spec.

that passed: both talkers recognised, bad checksums rejected, lat/lon correct to
9 decimals, knots converted, south and west negative, empty fields handled, and
the clock still readable from a sentence with no fix yet.

attitude.c, trip.c and elevation.c are the same - 39, 31 and 15 checks. all four
are pure numbers, and that is the only reason any of this could be proven before
the board existed.

one thing learned the hard way, below: a test that builds its fake inputs using
the same assumption the code makes will pass while both are wrong.

## pitch and roll

two angles is all the car needs:

  pitch   nose up or down, going up a hill
  roll    leaning to one side, cornering or a cambered road

+ pitch is nose up, + roll is right side down, axes X forward, Y left, Z up.
that combination is ISO 8855, what the car industry uses - so anything i read
about vehicle dynamics matches my code without flipping signs in my head.

yaw is not in here. gravity cannot see it, for the reason in the mounting
section, and the GPS gives heading anyway.

## why one sensor is not enough

the accelerometer alone can do it. sitting still it measures gravity, so the
direction it feels is the tilt:

  pitch = atan2(ax, sqrt(ay² + az²))
  roll  = atan2(ay, az)

careful with the first - most code online has a minus in front of ax, and that is
for axes with Z pointing down. mine has Z up. i copied the minus, it was wrong,
and the section further down is how long it took to notice.

the problem is it measures every force, not just gravity, and cannot tell them
apart. not a cheap sensor problem, physics - a push and gravity feel the same.
brake at 0.5 g and it adds 0.5 g backwards onto 1 g down; the total points
26.6 degrees off vertical, and the maths cheerfully reports the nose diving
26.6 degrees on a flat road.

the gyro alone can also do it - turning speed x time added up gives angle, and
gravity is not involved, so braking does not bother it. the problem there is the
zero offset. up to ±1 dps while perfectly still: 1 degree after a second, 60
after a minute, and it never comes back.

so the accel is right in the long run and wrong for a moment, the gyro right for
a moment and wrong in the long run. exactly opposite, which is why the fix below
works.

## the complementary filter

one line per axis, per sample:

  angle = a * (angle + gyro_rate * dt) + (1 - a) * angle_from_accel
  a     = tau / (tau + dt)

mostly keep where the gyro says i am, nudge a little towards where the accel says
i am.

a is just under 1 - at tau = 2 s and dt = 1/104 s it is 0.995. so 99.5% gyro and
0.5% accel every sample. sounds like the accel does nothing, but it votes 104
times a second and those add up: gyro drift gets pulled out continuously, while a
bump lasting a tenth of a second barely moves anything.

"complementary" because the weights add to 1 and each sensor is used where the
other is bad. a low-pass on the accel and a high-pass on the gyro, added.

the fancier version is a Kalman filter. same job here, far more code and far more
to tune. not worth it.

## what happens to one sample

  1. take the gyro offset off, in the board's own axes
  2. rotate both vectors into car axes
  3. check the total length of the accel - gravity, or the car pushing?
  4. if gravity, work out pitch and roll from it
  5. step the previous angles forward with the gyro
  6. blend 5 with 4, or keep only 5 if step 3 said no

## tau, and how i settle it later

tau is the only knob, in seconds, and it is the crossover: shorter than tau
believe the gyro, longer believe the accel.

two errors pull opposite ways:

  gyro side    a leftover offset b gives a standing error of b x tau degrees.
               1 dps at tau 2 s is 2 degrees. wants tau small.

  accel side   a fake tilt of f degrees lasting T seconds leaks in as
               f x (1 - e^(-T/tau)). a 0.5 g brake held 3 s at tau 2 s puts 20 of
               those 26.6 degrees into the answer. wants tau big.

no value is acceptable for both. that is what makes the two fixes below not
optional - they shrink each error at its source instead of trading one for the
other: measure the gyro offset and subtract it so b stops being 1 dps, and gate
the accel so the big fake tilts never reach the filter.

with both in, anything from 1 to 5 s works and the exact number stops mattering.
2.0 s is in attitude.c as a starting point, not a measured value.

how i settle it properly: log raw accel, raw gyro and the filter output on one
drive, replay on the mac with different tau, keep whichever tracks a known
manoeuvre best - a speed bump taken slowly, or a car park ramp whose slope i can
measure.

sensor noise never comes into this. gyro noise is 27 mdps, accel noise 0.03
degrees of tilt. the road and the driver are thousands of times bigger. this
filter fights driving, not electronics.

## the mounting angle

the case will not sit flat - tilted maybe 40-45 degrees towards the driver so the
screen is readable, with the accelerometer soldered flat on the board inside it.

that does not matter, as long as the tilt never changes and i handle it right.

the wrong way is to measure pitch and roll at rest and subtract them from every
later reading. fine for a few degrees, broken at 45, because pitch and roll are
angles and not parts of a vector - they do not subtract. with the board tipped
back, a pure roll of the car shows up partly as pitch. about 70% of the signal
lands in the wrong channel at 45 degrees.

the right way is to rotate the readings before any angle maths. the board-to-car
relationship is one fixed 3D rotation R:

  a_car = R * a_board
  g_car = R * g_board       (turning speed is a vector too, same R)

then the two arctangents run on numbers that look like they came off a flat
board. 9 multiplies per vector, two vectors per sample. nothing on a 180 MHz chip
with an FPU.

where R comes from: park on flat ground, read the accelerometer once. that one
reading is the measurement of my mounting angle - including the couple of degrees
of slop from the case and the dash not being level, which i could never have
typed in by hand. attitude_set_mount builds R from it (Rodrigues' formula, closed
form, no looping). so what gets hardcoded is three readings, not nine matrix
entries.

it cleans up the accelerometer's own ±20 mg zero error for free too, worth 1.15
degrees of permanent tilt, because that error is sitting inside the recorded
reading.

one catch: gravity gives 2 of the 3 parts of a rotation, never the third. it says
which way is down, so tilt is pinned completely, but it says nothing about
turning about the vertical - the sensor cannot tell whether the case faces
forwards or sideways, both look identical to gravity. that part comes from how i
build the mount, and lives in the axis map, not in attitude.c.

## the gate

if the accelerometer is not reading about 1 g in total, the car is pushing on it,
so that sample's accel half gets skipped and the gyro carries the angle alone.

|a| = sqrt(ax² + ay² + az²), and outside 1 ± 0.1 g the accel gets no vote.

  hard braking 0.5 g     |a| = 1.118    26.6 deg of fake tilt    caught
  cornering 0.3 g        |a| = 1.044    16.7 deg                 missed
  gentle push 0.15 g     |a| = 1.011     8.5 deg                 missed
  pothole                all over       big                      caught

the misses happen because a sideways push added onto 1 g down grows the total
length only as sqrt(1 + x²), which barely moves for small x, while the angle
error grows straight away. tightening to ±3% would catch more, but then almost
nothing passes on a rough road and the gyro drifts unchecked.

so it is a partial fix and i know exactly how partial - the host test feeds 0.2 g
for 3 seconds and expects about 8.8 degrees of error. measured and written down
instead of hidden.

the shape of the error makes it liveable: it builds while the push lasts and
decays on its own once it stops. nothing accumulates, nothing needs resetting. on
the display it reads as the trace drooping for a few seconds during a long pull.

the full fix, later: i already know the car's real acceleration from elsewhere -
forwards from the change in GPS speed, sideways from speed x yaw rate off gyro Z.
subtract those and what is left really is gravity. the sideways one should work
well at 104 Hz; the forwards one only partly, GPS speed updates once a second.
bumps stay uncaught either way.

## the sign that will bite me

the accel formulas and the gyro axes do not line up the way i first expected.
roughly level it comes down to:

  pitch_rate = -gyro_y
  roll_rate  = +gyro_x

the minus is real. with Y pointing left, a nose-up rotation is a negative turn
about Y by the right hand rule.

writing it down because getting it backwards does not blow anything up - the gyro
half and the accel half just pull against each other and the output looks slow
and laggy rather than obviously broken. that kind of bug survives for weeks.

those two lines are only the level-ish version. once the car is properly tilted
its axes are tilted too and they mix. the full form is below, and it is what is
in the code.

the host test has a line for each sign: spin one axis at 10 dps for a second with
the accel gated out, check the angle comes out +10.

## off-road is where the shortcut breaks

good news first: off-road is the easy case for this filter. crawling over rocks
the car barely accelerates - 0.1 or 0.2 g against 0.5 g of braking on tarmac - so
the accelerometer is nearly telling the truth and the gate lets most samples
through. the regime it struggles in is motorway braking, which is exactly where
the angle does not matter.

also fine: atan2 is exact at 40 degrees the same as at 4, no small-angle
approximation anywhere. and the mount rotation saves me from a trap - with the
case tilted 45 back, a car pitched 40 puts the sensor at 85, right next to where
this maths falls apart. but the rotation into car axes happens first, so the
maths only ever sees the car's 40. the awkward point is 90 degrees of car pitch,
which is a rollover, not a hill.

what was not fine: those two gyro lines. the full version is

  pitch_rate = -cos(roll) x gyro_y + sin(roll) x gyro_z
  roll_rate  = gyro_x - tan(pitch) x (sin(roll) x gyro_y + cos(roll) x gyro_z)

both collapse to the short version at zero. what the short one costs:

  10 degrees of tilt      1.5% out    ~0.05 deg of error, invisible
  30 degree side slope    13% out     ~5 deg, and it stays
  40 degrees, turning     worse       yaw rate leaks into roll through tan()

that last one is climbing across a side slope while turning, which is normal
off-road. and the error does not fade - it lasts as long as the manoeuvre,
because the gyro keeps integrating wrong and the accel only pulls back a little
each sample.

fixing it costs two sin, two cos and one tan per sample - about 0.04% of the
processor at 104 Hz. tan() runs away at 90 degrees so the pitch fed into it is
capped at 80, already a rollover.

past about 60 degrees the right answer would be quaternions instead of angles,
but 60 degrees of pitch means the car is going over.

one more thing that matters more off-road: reading the sensor every 100 ms while
it produces 104 a second throws away 9 out of 10. on tarmac the angles barely
move between samples. off-road they do - at 60 dps the car moves 6 degrees
between two - and the thrown-away samples alias vibration into the kept ones. so
INT1 is not a nice-to-have for this.

## the sign i got wrong, and how the test hid it

worth writing down because it is the exact failure the section above warns about.

i had the accel formula as pitch = atan2(-ax, ...), which is what most code
online has. wrong for my axes; the right one has no minus.

why: an accelerometer at rest reads +1 g on whichever axis points up, so what it
hands back is the "up" direction as seen from the car. nose up tilts the forward
axis towards up, so the forward number goes positive. the version with the minus
comes from books using Z down, and it does not survive being copied across.

what makes it worse than a flipped display: the gyro half had the sign right and
the accel half had it wrong, so the two would have pulled against each other
forever and never settled - the "looks sluggish instead of broken" bug. i wrote
that warning while the bug was already sitting in the file.

how it hid: my test built its fake accelerometer readings with the same wrong
sign, so both halves agreed and everything passed. a test that shares an
assumption with the code cannot catch that assumption.

what caught it: a separate little program that rotated a vector directly, with no
angle formulas in it at all. that is the lesson - to check maths, check it
against something that does not work the same way, not a tidier version of
itself. the numbers from that program are now the expected values in the test.

## trip stats

everything that only makes sense across a whole drive. one session per power-on,
because the ignition cuts the power and there is nothing to resume.

  how long        total, and the part actually spent moving
  how far         speed x time
  how fast        the highest GPS speed
  how hard        peak push forwards, backwards and both sideways
  how far leaned  biggest pitch and roll each way
  how close       those two against what the car can actually take
  the weather     min, max and average of temperature, pressure, humidity

the module has no clock. time arrives as a dt on every motion update. same reason
as the parser - no HAL means it runs on the mac.

## a float that grows starts rounding

a float holds about 7 meaningful digits. plenty for one reading, but a running
total eats its own digits as it grows - the bigger the number, the coarser the
steps near that value.

the trip timer adds about 0.0096 s per sample. past two and a quarter hours the
smallest step a float can make up there is about 0.001 s, so every addition gets
rounded. and because the added amount is identical every sample, the rounding
error is identical too - it stops averaging out and the timer runs fast, up to a
minute per hour. distance has the same disease, worst on a motorway at constant
speed.

the fix: whole seconds and whole metres live in plain integers, which never
round, and only the part below 1.0 lives in a float, which never grows. every
update adds into the fraction and carries the whole part across, like a clock
carrying seconds into minutes.

## taking gravity out first

the accelerometer reading always has gravity in it. park on a 10% slope, which is
5.7 degrees, and the forward axis reads sin(5.7) = 0.1 g forever. leave that in
and the "hardest braking" of a mountain trip is the car sitting still on a hill.

so the first thing that happens to every sample is subtracting where gravity is
pointing, known because the attitude filter just worked out the angles:

  gravity_x = sin(pitch)
  gravity_y = cos(pitch) x sin(roll)

what is left is what the car is doing. also why the coasting below can work at
all - integrating a number with gravity still in it would have the car
accelerating up every hill.

## the accelerometer reads the push, not the feel

which side was the hardest corner on - easy to get backwards.

in a bend two directions are in play. the tyres push the car toward the inside -
that is the real force, the one that makes it turn. the feeling of being thrown
toward the outside is the fictitious one, same as being pressed into the seat
under acceleration.

the accelerometer measures the real one. same rule as reading +1 g up while
parked - that is the ground pushing up, not gravity pulling down. so a left-hand
bend, tyres pushing the car leftward, reads positive on Y and lands in
accel_peak_left_g; the right-hand bend is the negative number.

## why the peaks are smoothed first

at 104 Hz a pothole is a single sample reading 2 or 3 g. record peaks off the raw
numbers and that one sample is the hardest braking of the trip.

body movement is all under about 5 Hz, impacts are far above it. so a 5 Hz low
pass keeps the first and drops the second, and only then are peaks recorded:

  y += alpha x (x - y)      alpha = dt / (tau + dt)

with tau = 1/(2 pi x 5) = 32 ms. writing alpha from dt means changing the sample
rate later does not quietly change the filtering.

two speed gates on top:

  3 km/h   below this the odometer stops, so it does not creep at a red light
  5 km/h   below this no push is recorded - a door slam is not cornering

lean angles use the lower gate on purpose. crawling over a rock at 4 km/h is
exactly when the tilt matters most, while a 4 km/h shove is not a manoeuvre.

## coasting when the GPS goes

a tunnel or an underground car park and the sky is gone. speed then comes from
the accelerometer: speed = speed + acceleration x time.

that only works for a while, because the error grows with the guessing:

  5 s      0.05 m/s out    about 0.1 m of distance
  30 s     0.3 m/s         about 4 m
  120 s    1.2 m/s         about 70 m
  5 min    3 m/s           about 450 m

so it gives up after 2 minutes and freezes the distance rather than inventing
more.

the good bit: if the guessed speed reaches zero it stays there until something
clearly pushes again - 0.05 g held for half a second. stopping resets the
accumulated error to nothing, so a tunnel where the car actually stops comes out
more accurate than one where it crawls the whole way. that has a name in
navigation, a zero velocity update.

while coasting there is no independent measurement of acceleration any more, so
the compensation handed to the attitude filter is set to zero rather than fed the
accelerometer's own guess. feeding a number back into the thing it came from is
how a filter starts believing its own mistakes.

## what gets handed back to the attitude filter

the whole point is that the two numbers come from somewhere other than the
accelerometer:

  forwards   how the GPS speed changed since the last fix
  sideways   speed x how fast the car is turning, from gyro Z

neither touches the accelerometer, so subtracting them actually tells you
something. subtracting a number derived from the accelerometer would just be the
accelerometer agreeing with itself.

the turn rate gets clamped to what the car can physically do at that speed first -
see vehicle_info.md. one corrupt gyro sample would otherwise shove a huge false
correction into the filter.

there is a loop here: the attitude filter needs the compensation, and the
compensation needs the pitch to remove gravity. broken by using last cycle's
numbers, one sample old at 104 Hz, which is 10 ms. normal, and what every control
loop does.

## elevation

two ways to know how high the car is, both bad alone:

  GPS altitude   right on average, jumps around by tens of metres
  air pressure   very smooth, slides with the weather over hours

opposite errors again, so the same complementary filter as pitch and roll, only
much slower - tau 60 seconds instead of 2.

turning pressure into height needs today's sea level pressure, which changes with
the weather and cannot be known. so the absolute number from the barometer is
always wrong. its changes are right though, and changes are all the filter wants
from it - the GPS supplies the absolute part.

  height = height + (what the barometer moved) then leaned towards the GPS

climb is added up from the combined figure, never the barometer alone, because a
weather front would otherwise register as a mountain - about 8 m of false height
per hPa the weather moves.

the climb count has a 3 m deadband so noise wobbling either side of one height
adds nothing. without it a flat motorway slowly accumulates a mountain range. the
test has a case for exactly this, and my first attempt used a wobble of 1.5 hPa,
which is 12 m - a real hill, not noise. the deadband was right and my test was
wrong.

## the car itself is a number now

App/Inc/vehicle_axes.h holds everything specific to the car and the mount, so
moving the board to another car is one file and a rebuild.

the car is an audi a4 b6 avant 1.8T 190hp quattro, 2004, 6-speed manual.
everything except the two centre-of-gravity numbers comes off its own data
sheet - the full table is in vehicle_info.md.

the useful part is that the car's shape feeds the maths:

  track width and cog height     how much sideways g tips it over
  cog to the rear axle           how steep a climb tips it backwards
  turning radius                 the fastest it can possibly turn

so the trip stats do not just say "0.4 g of cornering", they say how close that
was to putting the car over - the number that means something off-road. mass,
length and height are in there too but nothing calculates with them; they are for
the log, listed separately so it stays obvious which ones matter. mass is 1650 kg
and not the 1530 kerb figure, because the car never drives empty.

formulas and worked examples: docs/vehicle_info.md.

## timers and pwm, enough to follow tim.c

a timer is a counter that ticks at some speed and wraps to zero at a limit. two
numbers set everything:

  prescaler   divides the clock feeding the timer; the result is the tick
  period      how many ticks make one cycle before the wrap

both are hardware "value plus one", so prescaler 83 divides by 84 and period 999
means 1000 ticks per cycle.

the timers do not all get the same clock. TIM2 and TIM5 sit on the slow bus and
are fed 84 MHz; TIM1 sits on the fast one and gets 168 MHz. that is why TIM1
needs prescaler 167 for the same 1 MHz tick the others get from 83.

pwm is the timer driving a pin: output stays high until the count passes a third
number, the compare value, then goes low until the wrap. the fraction of each
cycle spent high is the duty cycle, and that is the actual knob. the flipping is
done by the timer hardware, no code runs per cycle.

  TIM1   1 MHz tick, period 999     1 kHz pwm, 1000 duty steps - backlight
  TIM2   1 MHz tick, period 99999   10 Hz - bench value for the header pin
  TIM5   1 MHz tick, period 99999   10 Hz - same, the other header pin

the backlight numbers can stay: 1 kHz is far above visible flicker and 1000 steps
is plenty. the two header timers are placeholders - whatever daughterboard uses
them brings its own numbers.

## why the chip selects idle high

chip select tells one chip "this bus traffic is for you". active low - low means
selected, high means ignore the bus.

cubemx asks what level every output pin starts at, and the default is low. for
the three chip selects that would mean every chip wakes up already selected:

- an sd card in spi mode wants at least 74 clock pulses with its chip select held
  high before it will enter spi mode. boot with the pin low and that quietly
  fails until code fixes the pin
- a selected display treats whatever appears on the bus as commands, so stray
  startup traffic could leave the controller in a state the init code does not
  expect

so all three start high, set in cubemx so a regeneration keeps it.

the display reset pin is the opposite on purpose: it starts low, holding the
panel in reset until the init code wakes it into a known state.

## printf over usb

at this point the board could not tell me anything. i had no debug probe yet, so
no breakpoints and no watching variables, and the only output was an LED. enough
to prove the timers run; useless for "did the sensor answer" or "is z reading
1.00 or 0.98". (i got an ST-Link V2 clone later, after step 5 - see the swd
section near the end. the usb console still matters, it is the only channel that
exists in the car.)

the fix is the usb-c cable already plugged in. it already worked - dfu-util
flashes through it - so the connector, the traces and the 48 MHz usb clock were
proven before i started. what was missing was software.

a usb device has to say what kind of thing it is. there is a standard kind called
CDC, communication device class, meaning "i am a serial port", and every OS ships
a driver for it. once the firmware claims to be CDC the mac makes a file at
/dev/cu.usbmodem... and screen reads it like a terminal. no new wire.

## what happens when i plug it in

plugging in does not just start working. the host runs a short interview first,
called enumeration:

- it holds the data lines in reset
- it asks who are you, what class, how much power, what pipes do you have
- the device answers with descriptors - small fixed byte tables in the firmware
- only at the end does the host say "configured"

before that last word the device cannot send anything and my buffers do not exist
yet. that is why usb_serial_ready() checks for the configured state before every
send. printing earlier would not just be lost, it would crash - the cdc code
follows a pointer that is null until the host configures the device.

the port name comes out of that interview too. mine is
/dev/cu.usbmodem204A396852301 and that number is this chip's own serial number,
burned in at the factory. a second board would get a different name.

cubemx deleted Core/Src/usb_otg.c when i added the middleware. correct, not a
mistake - the hardware setup moved into usbd_conf.c because the usb stack owns
that layer now. keeping both would initialise the same peripheral twice.

## making printf go somewhere

on a pc printf hands its bytes to the operating system. there is none here, so
the chain has a missing bottom end:

  printf()          formats the text
  newlib            the c library
  _write()          "send this block somewhere"
  __io_putchar()    "send this one character somewhere"
  usb_serial.c      actually sends it

_write already exists in Core/Src/syscalls.c but it is marked weak, so the linker
throws it away the moment a real one turns up. it loops over __io_putchar, and
that is the hook i fill in - so i plug into the gap without editing a generated
file.

two things that bit:

- newlib keeps a buffer of its own above all this and holds output until about a
  kilobyte piles up. setvbuf(stdout, NULL, _IONBF, 0) turns that off
- the linker uses nano.specs, a cut-down c library that leaves floating point out
  of printf. %d works, %.2f prints nothing useful. -u _printf_float pulls it back
  in and costs 11.8 kB, measured on this toolchain. worth paying - every number
  the sensors give me is a float

## why there are two buffers

sending one character at a time over usb would be slower than the printf itself,
so __io_putchar only appends to a buffer and the whole line goes out on the
newline.

the catch is that CDC_Transmit_FS does not copy anything. it stores a pointer and
returns straight away; the real copying happens later inside the usb interrupt.
so this is wrong:

  CDC_Transmit_FS(buf, used);
  used = 0;                  // printf starts overwriting buf
                             // while the interrupt is still reading it

the result would be scrambled lines that come and go with timing. two buffers fix
it: hand one over, fill the other.

same family of trap as HAL_UART_ErrorCallback in uart_bus.c - a hardware job that
outlives the function call that started it.

## nobody is listening

usb devices never start a transfer. the host asks "anything for me?" and the
device either hands over a packet or says NAK. if no program has the port open
the mac stops asking, the queued packet sits there forever, and CDC_Transmit_FS
keeps answering busy.

so every send has a 10 ms timeout and throws the line away when it runs out.
without it the firmware would freeze in that loop the first time nothing is
attached - which is every time it runs in the car.

characters thrown away like that are invisible by nature, so they get counted,
same idea as uart_bus_overruns(). the first run showed drops 149 before screen
was attached, and 149 is exactly the banner plus the first tick line added up by
hand. the moment screen opened it froze and stayed frozen.

## the sensors answered

step 1 was the first time the firmware talked to another chip. up to here it was
all the stm32 talking to itself - timers, clocks, usb.

call imu_init() and env_init() once, print whether they worked, then read both
every second. both said OK first try.

i put a bus scan in front of them. it walks every 7-bit address from 0x08 to 0x77
and sends just the address with no data, then looks at whether anything pulls the
line low to answer - the ACK from the I2C section above.

the point is telling two failures apart. if imu_init() fails on its own i cannot
tell whether the part is dead, the address is wrong, or the whole bus is down:

  both 0x6A and 0x76 answer   bus and soldering fine; a register is the problem
  nothing answers at all      bus level - pull-ups, the two pins, or power
  only one answers            that one part's solder joints

worth ten lines because every flash means moving the boot jumper by hand.

the drop counter did its job again. it stood at 1352 before screen attached and
never moved after. counting by hand - the banner, then seven seconds of readings
at five lines each, with a carriage return on every line - comes to about 1363
bytes.

## a state and a rate

the thing that confused me watching the numbers.

the accelerometer measures a state: which way is down right now. tilt the board
and hold it, the numbers change and stay changed.

the gyroscope measures a rate: how fast am i turning right now. rotate it and it
reads maybe 80 dps while my hand moves; stop and it drops back to nearly zero, no
matter which way the board ended up facing. it has no idea where it is, only that
something is changing.

so a gyro trace is spikes while something moves and flat the rest of the time,
and a board sitting still reads zero whichever face is down. correct, not a
fault.

why keep both:

  accelerometer   honest over the long run, useless while moving; it cannot tell
                  gravity from acceleration, so braking hard looks like the world
                  tilted

  gyroscope       ignores that completely and reacts instantly, but the angle
                  only comes from adding the rate up, and adding up a wrong
                  number adds the wrongness up with it

my own readings show why. the board is dead still and the gyro reads about
+0.45 dps on X - in spec. but add it up: 0.45 x 60 = 27 degrees of turn per
minute that never happened. that is the drift the complementary filter exists to
remove, and this is the first time i have seen it as a number off my own board.

## sensor axes and car axes

two coordinate systems are live at once, and mixing them up cost me an argument
with myself.

  sensor frame   what the LSM6DSO reports. fixed by how the chip is soldered.
                 flat board reads -0.990 on Z, forever, and that is correct
  car frame      X forward, Y left, Z up. what everything above imu.c expects

vehicle_map() is the only thing that crosses between them. nothing below it knows
the car frame exists.

the 1 Hz debug line prints the sensor frame on purpose - raw truth, and if it
ever changed i would want to see it. the calibration block prints the car frame,
because that is where the constants live. so "Z still reads -0.990" is not a bug
report, it is the lower layer doing its job. the test is whether the mapped Z
reads positive, and it does.

## the chip is upside down

the pass criterion i wrote for step 1 said a flat board should read about +1 g on
Z. it reads -0.990.

an accelerometer at rest reads +1 g on whichever axis points up. the LSM6DSO's +Z
comes out of the top face of its package, and the chip is soldered to the bottom
of the board, so that face aims at the table. +Z points down, Z reads minus one.
the mounting, not a fault - i wrote that criterion before thinking about which
side the part is on.

what it changes: attitude.c wants Z up. feeding it the raw sensor Z would give
exactly the sluggish tracking the sign section warns about. the fix belongs in
the axis map, not in attitude.c.

## working out the axis map

step 2. one rule does all of it: an accelerometer reads +1 g on whichever axis
points up. everything else is bookkeeping.

  1. picked a forward - the edge opposite USB-C
  2. flat: sensor Z reads -0.990, so sensor +Z points at the table
  3. nose up: sensor X went to +0.71, so sensor +X points forward
  4. right side down: sensor Y went to -0.61, so sensor +Y points right

car axes want X forward, Y LEFT, Z up. so X survives, Y flips, Z flips.

the flip is not about how the board gets mounted in the car - it is only about
which side of the PCB the chip is on. take a book: arrow forward on the cover,
arrow left, arrow up out of the cover. flip it over about the forward arrow.
forward is still forward, up now points at the table, left now points right. one
motion, two arrows reversed. that is the chip.

flipping only Z would be a mirror, and no rigid rotation makes a mirror. the
check is the determinant: (+1)(-1)(-1) = +1 is a rotation, -1 would mean i made
an error.

then i checked it by running the three real tilt readings back through
vehicle_map() on the mac. nose up gave +46 degrees of pitch and right side down
gave +38 of roll, and attitude.h says + is nose up and + is right side down. both
right. drop the Y minus and roll reads -38 - the display leans the wrong way
while still looking plausible, which is the failure mode that hides.

the map only expresses quarter turns and flips. the actual mounting angle - the
40-ish degrees the case will sit at - is not in it at all; that goes in the rest
accel reading.

## what the bench numbers are worth

board flat, everything inside what the datasheet allows:

                        measured             datasheet allows
  accel X               +7 to +16 mg         +/-20 mg zero-g offset
  accel Y               +1 to +4 mg          same
  accel Z magnitude     0.988 to 0.992 g     +/-1% sensitivity tolerance
  gyro, all three       0.31 to 0.56 dps     +/-1 dps zero-rate level

nothing out of tolerance, which is the real result - the parts and the joints are
good.

then something i did not expect. the same board reads differently on a mouse pad
and on a wooden table:

  mouse pad    ax = +0.015     tilt = atan2(0.015, 0.990) = 0.87 degrees
  wood         ax = +0.0075    tilt = atan2(0.0075, 0.991) = 0.43 degrees

about 0.43 degrees flatter on wood - the foam squashes unevenly under the
through-hole solder tails.

the catch is that the absolute number is not trustworthy. up to 20 mg of that X
reading could be the sensor's own zero error rather than tilt, and 20 mg is worth
1.15 degrees. so i cannot say "the board is tilted 0.87 degrees", only "these two
surfaces differ by 0.43", because the zero error is the same in both and cancels
out of the difference.

which is exactly why the rest reading is stored as a calibration constant instead
of assumed to be zero. it measures the tilt and the zero error together, and for
cancelling them both out that is all that is needed.

practical: calibrate on the hard table.

## judging an average

the calibration prints two spreads and they answer different questions:

  peak-to-peak in one run   was the board still?
  spread between runs       is the thing i am measuring stable?

mine came out 0.003-0.007 g and 0.105-0.175 dps within a run, matching the
datasheet noise density (75 ug/sqrt(Hz) accel at ±4 g, 3.8 mdps/sqrt(Hz) gyro, at
about 52 Hz of bandwidth). so nothing bumped the table.

when the between-runs spread is larger than the within-run p-p, the thing is
drifting, not noisy. that is exactly what gyro X did - 0.19 dps between runs
against 0.12 within one. two spreads, two different diagnoses, and one number
alone cannot give you that.

## the gyro offset moves while the board warms up

the zero-rate level is not one fixed number.

  just powered      gyro X = +0.42 dps
  21 minutes in     gyro X = +0.61 dps      and still climbing

Y and Z settled straight away - 0.002 and 0.006 dps across four runs. only X
drifts.

so the board has to be warm before the 500 samples get averaged, and warm is
longer than i guessed. i said five minutes; twenty was not enough.

what i cannot do is blame a number on it. the BME680 only moved 2.3 C over that
window, which would make the drift 0.080 dps per degree, eight times the
datasheet's typical. but the BME680 sits in its own self-heated pocket that
saturates in the first minute, while the IMU die warms on a slower curve. wrong
thermometer, so that figure means nothing. the LSM6DSO has its own temperature
register if this ever needs doing properly.

why i stopped chasing it: the leftover 0.2 dps is 0.4 degrees of standing error
at tau 2 s, and the car's own 40 degree temperature swing causes 0.8 degrees
regardless. halving the smaller of two errors is tidiness, not engineering.

## the bme680 warms itself

the temperature reads high - about 30-31 degrees, above the room.

expected, and the datasheet says so - the reading tracks pcb temperature, the
sensor's own self-heating and the ambient together, and sits above ambient. no
surprise with a 300 degree plate firing for 100 ms every second a millimetre from
the die, next to a 168 MHz chip and an LDO.

the humidity follows it. relative humidity is a ratio against how much water the
air could hold, and warmer air could hold more, so the same water reads as a
lower percentage. the sensor is not wrong - it is correctly reporting its own
warm pocket, which is not the room.

i can back the room out of it. with the sensor at 31.0 C and 29.1 %RH:

  room 24 C  ->  43.9 %RH
  room 25 C  ->  41.4 %RH
  room 26 C  ->  39.0 %RH
  room 27 C  ->  36.7 %RH
  room 28 C  ->  34.7 %RH

nothing is broken - pressure is sane at 1005-1006 hPa, gas responds to breath,
and T and RH are consistent with each other.

not calibrating the offset yet though. at 1 Hz the heater runs 10% of the time;
BSEC's low-power mode measures every 3 s, about 3.3% duty and a third of the
heat. measuring an offset now would calibrate it against a duty cycle i am not
going to ship. that belongs with BSEC.

the gas resistance climbs the whole time a session runs - 16 kohm at eight
seconds, 27 kohm at a minute, plateauing near 51-57 kohm. the metal oxide layer
burning off what it picked up sitting in a drawer; higher resistance means
cleaner air. bosch tracks this in bsec with two flags, one for the very first use
after production and one for every switch-on after. more evidence that raw ohms
are not an air quality number.

breathing on it drops the resistance, which is the right direction - the vocs
make the layer more conductive. a finger on the package pushes temperature and
humidity up together, also right.

one thing i wondered about and then answered: the humidity kept falling while the
temperature was flat, which the ratio does not explain. it settled and stopped,
so it was the sensor equilibrating, not a runaway.

## the gps talked first time

one flash, one screen, the whole chain proved. i print counters every second:

  bytes     everything the UART received
  sent      complete $...* sentences
  rmc gga   what parsed
  other     good checksum, a type i ignore - GSV, GSA, VTG, GLL
  bad       checksum failed - noise on the line
  ovr       ring buffer overflowed

read it as a ladder. bytes stuck at 0 = no signal on the pin. bytes moving, sent
0 = wrong baud. sent moving, rmc 0 = parser. all moving = fine. first run: 261
bytes a second, exactly, rmc and gga +1 each, bad 0, ovr 0. wire, baud,
interrupt, ring and parser done in one go. the counters stay in for the car -
bad climbing means the line is picking up noise.

## the time was fake

first screen said 23:59:45 05/01/80 and rolled over to 06/01/80. that is GPS
time zero - 6 january 1980. the module fills the time fields from the first
second on and just counts up from the epoch until it hears a satellite. my
time_valid only meant "the fields were not empty", so it was true on garbage.

fixed in gps.c: time_valid only when the year is 26 or later and below 80. the
two digit year makes 1980 look bigger than 2026, hence both ends.

## sats 0 means less than i thought

the number in GGA is satellites used in the fix. it stays 0 right up to the fix,
so it cannot tell "antenna hears nothing" from "not enough yet". GSV has the
in-view count but i do not parse it. free proxy: bytes per second. with nothing
heard every GSV is the empty $GPGSV,1,1,00*79 and the total is 261. as
satellites appear GSV grows and the number climbs. about 650 with a fix.

## twelve minutes of sky, zero satellites

open sky on the balcony, 261 bytes a second for 12 minutes. the module is
-149 dBm sensitive and the sky hands you about -130; nothing "a bit off" loses
19 dB. either an open somewhere or the antenna was not an antenna.

multimeter, board off:

  antenna port to RF_IN          0.2 ohm   the trace
  antenna port to ground         0.4 ohm   the antenna's own element; a solder
                                           bridge at the module would read 0.2
  antenna ground pad to ground   0.0

board on: V_BCKP present. nothing open, nothing shorted, backup domain fed.
electrically perfect, so it had to be the RF part.

## the keepout i never made

a chip antenna is not the antenna. it is a small ceramic resonator that drives
currents into the ground plane, and the plane does the radiating. it wants
ground beside it and none under it. copper 0.2 mm below it (F.Cu to In1)
mirrors the field and cancels it, and pulls the resonance far from 1575 MHz.
easily 20-30 dB. that is the whole story.

the datasheet never says it. the table says "ground plane 50 x 100 mm", which
is the counterpoise next to the antenna, and the only place the clearance
exists is the drawing: hatched = copper, blank = nothing, and the antenna sits
in a blank 7.8 x 12 mm box in the corner. two of us read that sheet and neither
saw it. the good manufacturers write it as a sentence: keep-out, no copper on
any layer.

my board has solid pour under the antenna on all four layers. the docs said a
keepout was there. it was the plan, never the copper. check the copper.

if a chip antenna ever goes on a board of mine again:

  corner, long side along the edge, 2.3 mm in
  7.8 x 12 mm rule area on all copper layers - no pour, no vias, no tracks
  module right next to it, feed a few mm, 50 ohm for the stackup
  pi footprint on the feed, 0 ohm fitted
  hide F.Cu and look at every inner layer - DRC does not catch this

or a patch antenna, which wants ground under it and forgives.

## how i fixed it, on this board

took the chip off, soldered it back on two pieces of THT resistor leg, so it
sits about 1 cm above its own pads with air under it. that is it. from the
balcony: fix, 9 satellites, hdop 1.2, quality 2 (EGNOS corrections). it holds
until it does not - that corner is fragile now.

if it breaks, the clean fix is a U.FL receptacle (hirose U.FL-R-SMT or i-pex
20279) on the antenna pads and a passive 25 mm patch on a cable with an MHF
plug - quectel YFGA025E3BM or DM, taoglas CGGBP254.07.0100A. passive only: the
board puts no DC on RF_IN, and an active antenna has an LNA powered through the
cable that blocks the signal when unpowered. the quectel AM is the active one,
the letter matters. for a rev B, the pocket above, or a patch.

## what the first fix taught me

  position   20-50 m off, drifting 30 m while still. hdop 1.2 says the geometry
             is fine, so that is multipath off the building. dash under a
             windscreen should give 3-5 m
  hold       the position freezes for long stretches then steps. the module
             pins it when it thinks it is stationary
  speed      0.0 with blips of 1.5-2 km/h standing still, about 0.5 m/s of
             noise. the odometer gate wants to sit around 3-5 km/h
  altitude   above mean sea level, not above the street. bucharest is roughly
             70-90 m, so 16 m is about 70 low. vertical is the weak axis and a
             balcony sees half the sky. check it under open sky before
             elevation.c trusts it
  time       UTC. +3 h here in summer, a display concern. also about 3 s off
             early on; the module uses a built-in leap second default until it
             downloads the real one, up to 12 min after a cold start. recheck
             after a long fix
  the gap    one second with no bytes and age 1.8 s, right when the time went
             real. the module re-aligned its second to gps time. harmless, the
             ring did not notice

## the backup cell

the ML2032 went in on 16 sep at 3.07 V and never held anything. by 19 sep i
could not read a voltage across it at all, and every start was cold - off for
10 s after a fix, the clock took ~12 s and the fix over a minute.

swapped in a CR2032 at 3.3 V: off 10 s, clock back instantly, fix in ~10 s.
so the V_BCKP path and the module are fine, the ML2032 is the problem.

careful: a CR2032 is not rechargeable and the board trickle-charges BT1. it
cannot stay in with the charge path connected. oct: no cell in for now, a new
ML2032 next, CR2032 with D3 out as the fallback - never R6, see back on the
bench.

## the baud rate that does nothing

screen /dev/cu.usbmodem 115200. that number is ignored. CDC carries a baud field
so a usb-to-rs232 adapter can pass it on to the real uart on the far side; my
board is the far side, so it reads it and does nothing with it.

what i actually have is usb full speed, about 1 MB/s of payload. the attitude
stream at 5 lines a second is 310 bytes/s.

so the wire was never the limit. the limits are my eyes and the 10 ms flush
timeout in usb_serial - both about how many newlines a second, not how many
bytes. that is why the fix was printing less often, not printing shorter lines.

## the filter rate and the print rate are not the same thing

sample -> compute -> decide whether to say anything. the first two run at
whatever the physics needs, the third at whatever i can read. tying them together
forces a choice between a slow filter and an unreadable console.

ATT_PERIOD_MS is the maths, ATT_PRINT_DIV is the console, and changing the second
cannot touch the first. when INT1 moves the loop to 104 Hz only the first one
disappears.

## a blocking read inside a loop

env_read sits in a busy wait about 143 ms while the heater plate comes up and the
bme680 converts. in a superloop that means nothing else runs - not the attitude
tick, not gps_poll draining a ring against a module sending 900 bytes a second.

with BENCH_SENSORS on it went like this once a second: two normal 100 ms ticks,
then one tick with dt 243 ms. the filter survives that because dt is measured,
but anything i did to the board inside that window is simply gone. so i turned it
off for the step rather than test through a hole.

the real fix is a non-blocking read - kick the measurement off, come back for it
later. that belongs with the task loop, not here.

## measuring dt instead of assuming it

tempting to pass 0.1f and be done. it is not 0.1 - the tick fires on the first
pass at or after 100 ms and the loop body varies, so it is 100, sometimes 101,
sometimes more.

an assumed dt turns every millisecond of jitter into an integration error that
never comes back. measuring costs one subtraction.

the subtraction has to be unsigned. HAL_GetTick counts milliseconds in a uint32
and rolls over to zero after 49.7 days; now - last in unsigned arithmetic wraps
the same way the counter did and comes out right, while now > last + period would
break. that is why every timeout in this codebase is a subtraction.

dtmax on the console is the audit for it. read 100 on every line for 200 seconds.

## the settling curve is the proof

best thing in the step 4 logs. front edge propped up, printed at 5 Hz:

  15.71  15.43  15.74  15.41  15.11
  14.82  14.57  14.34  14.14  13.96
  ...
  12.46  12.43  12.40  12.36  12.36   ->   12.22

two separate things going on.

the overshoot to 15.7 is the gyro. while i was moving the board the gate was open
so the angle came from the gyro alone, and at 10 Hz i integrate one instantaneous
rate over a 100 ms slice as if it held for the whole slice. during fast motion it
does not, so it overshoots. INT1 fixes that.

the decay back is the accelerometer pulling. alpha is 2/2.1 = 0.952, so each step
keeps 95.2% of the gyro answer and takes 4.8% of the accel one - an exponential
with time constant tau. 63% in 2 s, 95% in 6 s.

check it against the log: 3.49 degrees to remove, and six seconds later 3.25 of
it was gone. 93%. so tau is 2 s measured, not assumed any more.

and this is the pass criterion, not the static number. a sign fight never settles
- the two halves pull against each other so it creeps or hunts. mine overshot,
decayed cleanly from both directions and came back to zero after being waved
about. that is the thing to look for.

## the ruler has error too

the reference was asin(h/L) - prop one edge up by h, the board is the hypotenuse
of length L. nothing in it comes from the accelerometer, which is the whole
point; a test that shares an assumption with the code cannot catch that
assumption.

asin and not atan: h is the opposite side and L is the board itself, the
hypotenuse, not the horizontal projection. atan would have given 11.93 instead of
12.18 - a quarter of a degree, a quarter of my whole budget.

and the reference is not exact either:

  d(angle)/dh = 1 / (L x cos angle)

  pitch, L 61.6 mm     0.95 deg per mm    +/-0.5 mm is +/-0.48 deg
  roll,  L 95.79 mm    0.60 deg per mm    +/-0.5 mm is +/-0.30 deg

roll came out 0.29 off. that is not a 0.29 error, it is inside what the ruler can
resolve; the honest sentence is "agrees to the resolution of the measurement".

it also says how to design the next one - pick a big angle. the error is fixed in
millimetres, so it shrinks in relative terms as the angle grows.

## ruling out the firmware without touching the board

the usb-c edge read -8.90 where the geometry said -12.18. before blaming anything
i checked whether the code could even do that.

  pitch_acc = atan2(ax, hypot(ay, az))

flip the sign of ax and the answer flips exactly - the function is odd. no
setting makes it squash one direction and not the other. the only thing that
could skew the pair is a zero offset: true +A and -A would read +A-d and -A-d.
solve for d from my two numbers and it needs -1.66 degrees. but d is exactly what
a flat board reads, and flat read +0.01.

contradiction, so there is no offset, so the two edges really did reach different
heights. -8.90 back-solves to 9.53 mm instead of 13, and that edge is the one
with a rigid plug body hanging off it.

the shape of this is worth keeping: find a property the code has by construction,
then find the one observation that closes the loophole. cheaper than another
experiment and more certain.

## step 4 numbers

board is 61.6 x 95.79 mm, usb-c on a 95.79 edge - so fore-aft is 61.6 and
left-right is 95.79. propped 13 mm:

  front edge up     expected +12.18    read +12.22
  left edge up      expected  +7.80    read  +8.09
  flat              expected   0.00    read  +0.01 pitch, -0.15 roll

dtmax 100 ms on every line over 200 s, err 0, drops frozen at 2980 the whole run
- so 5 Hz plus the per-second block fits with room.

the gps year gate worked here too: time -- until about 190 s, then real UTC on
the right date while still showing fix no and sats 0. time arrives before
position because one satellite is enough to set the clock, four are needed to
solve for where you are.

## the sensor tells me instead of me asking

until step 5 the loop asked - every 100 ms it looked at the clock and decided it
was time to read. that is polling. it works, but the loop and the sensor are two
clocks that know nothing about each other, so i either read too often or miss
most of the samples. at 100 ms against 104 Hz i threw away 9 out of 10.

an interrupt turns it round. the sensor raises a wire when it has something, the
cpu stops what it is doing, runs a small function, and carries on.

the chain, every link of which had to exist:

  new sample                  LSM6DSO pulls INT1 high
  PB10                        sees a rising edge
  EXTI line 10                latches a pending bit
  NVIC                        sees EXTI15_10 pending, and enabled
  EXTI15_10_IRQHandler        runs
  HAL_GPIO_EXTI_IRQHandler    clears the pending bit
  HAL_GPIO_EXTI_Callback      my code

the pin was already GPIO_EXTI10 and already GPIO_MODE_IT_RISING from an earlier
cubemx pass, so the NVIC enable was the one missing link - the whole cubemx job
was one checkbox. on the sensor side INT1_CTRL bit 0 has to be set or the pin
never moves at all.

the pin defaults happened to match the board already: H_LACTIVE 0 is active high
and PP_OD 0 is push-pull, which is what rising-edge with no pull expects. so
INT1_CTRL was the only register i wrote.

## the latch, and the trap in it

COUNTER_BDR_REG1 bit 7 is dataready_pulsed and defaults to 0. the datasheet
calls that "data-ready latched mode (returns to 0 only after an interface
reading)".

so the line is not a pulse. it goes high and stays high until i read the output
registers. which means one edge per sample as long as i keep reading - and:

  if i ever stop reading, the line stays high, no new rising edge happens, and
  interrupts stop forever.

worth remembering because it looks exactly like a dead pin or a bad joint, and
it is neither. the fix would be "read the data", not "check the hardware".

the upside is it cannot get out of step. with BDU set (imu_init already does)
the registers hold until both halves are read, so i can never get a torn sample
or the same one twice. that is why i kept latched instead of pulsed - pulsed
gives a cleaner raw count but is not what i want to ship.

## why the handler does almost nothing

the callback is three lines: check the pin, bump a counter. on purpose.

while an interrupt runs, others at the same or lower priority wait. USART1 takes
an interrupt per received byte to feed the gps ring. if i did the i2c read inside
the handler instead - 14 bytes at 400 kHz, about 350 us of blocking HAL call - i
would be blocking that path 105 times a second. a 9600 baud byte arrives every
1.04 ms, so that is a third of the gap between gps bytes spent inside an
unrelated handler. that is how nmea characters start disappearing for no visible
reason.

same reason there is no printf in there - it formats a string, walks a buffer and
can sit up to 10 ms waiting on usb.

the rule: a handler records that something happened, the main loop decides what
it means.

priority while i was at it. USART1 sits at preemption 0, the highest; i put
EXTI15_10 at 1. on cortex-m lower number means higher priority, and a higher one
can interrupt a lower one that is already running. same number means neither
interrupts the other, they queue - so with both at 0 a gps byte would wait for my
handler to finish. the margin was never the problem, a few hundred ns against a
1.04 ms byte, but one dropdown made it impossible instead of just unlikely.

## edges and reads cannot drift apart

i print two counters, edges and reads, and they came out equal every second.
that is structural, not luck:

  edge -> line high -> loop reads -> line low -> next sample -> next edge

an edge needs a read before it, a read needs an edge before it. they alternate,
so edges minus reads is 0 or 1 at any moment. reads can never run ahead of
edges, and a slow loop shows up as both numbers dropping together rather than as
a gap between them.

which is why dtmax is the thing that catches a missed sample, not the counters.

it also settled the 105 question. the ODR is called 104 Hz and i measured 105.
a dropped sample would show as about 19 ms in dtmax; dtmax never went above 10.
so it is the chip's internal oscillator running about 1% fast, not me losing
slots. the datasheet on disk gives no ODR tolerance to compare that against.

  105 Hz -> 9.52 ms period
  HAL_GetTick has 1 ms resolution, so that reads as 9 / 10 alternating, max 10

which is exactly what was on screen.

## volatile

int1_edges is static volatile uint32_t. volatile tells the compiler this can
change behind its back - the handler writes it, the main loop reads it, and
nothing in the main loop's own code explains why it would ever change. without
it the optimiser is allowed to read it once, keep it in a register and loop
forever on a stale copy.

it is a 32-bit aligned variable on a 32-bit machine so the read is atomic -
no half-updated value can be seen, and i do not need to disable interrupts
around it.

## step 5 numbers

  int1  edges/s 105  reads/s 105  dtmax 10 ms  err 0

same on every second across 66 s, drops frozen, and it held while i moved the
board hard enough to swing the angles 150 degrees. dtmax never went over 10, so
not one sample was missed out of about 6900.

what did not change: tau is still 2 s. alpha went from 2/2.1 = 0.952 at 100 ms
to 2/2.0095 = 0.9953 at 9.5 ms - each step takes a much smaller bite of the
accelerometer, but there are ten times as many steps, so the time constant is
the same. flat pitch and roll reading the same as step 4 is the right answer,
not a sign nothing happened.

what did change is the aliasing. step 4's flick overshot 3.5 degrees because i
integrated one gyro sample as if its rate held for the whole 100 ms. same
approximation now, but over 9.5 ms slices, so the error shrinks with the slice.

two things i noticed and left alone:

  roll drifted 0.33 deg over the first 16 s, at a slowing rate. gyro X is the
  suspect - roll rate is mostly gyro[0], and X is the one axis step 2 left with
  0.2 dps of doubt. test is to leave it powered 20 min on something rigid and
  see if it flattens. inside the error budget either way.

  gps age walked from 341 ms at boot up to 975 at 24 min, then wrapped to 72.
  that is my one-second print and the module's one-second output sliding past
  each other, about 400 ppm apart. not the loop - it catches the ms boundary.
  could be the 12 MHz crystal, systick, or the module's own oscillator with no
  fix to discipline it; that last one is most likely and an open-sky fix would
  settle it. 400 ppm is 35 s a day - nothing yet, matters for log timestamps.

  pitch went past -90 while i was waving it about. atan2 cannot do that, so it
  is the gyro half integrating free - nothing clamps pitch the way wrap180
  bounds roll. next to 90 degrees of pitch the euler angles are singular and
  roll stops meaning anything, which is the quaternion limit i wrote about
  earlier. only shows up past a rollover.

## the debug probe, finally

got an ST-Link V2 clone after step 5. three wires to J1: SWDIO pin 1, SWCLK pin
2, GND pin 4. pin 3 is +3.3V and i leave it alone - the board is powered from
usb-c through its own LDO, and the clone's 3.3V pin is an output, so connecting
it puts two supplies on one rail.

no NRST on the header, so it is a hot-plug attach and a software reset. "connect
under reset" is not available and does not need to be.

usb-c stays plugged in the whole time. it is still the power and still the
console - and in the car it is the only cable, so the console has to keep
working on its own regardless.

what changed: flashing is one button in clion now. no BOOT0 jumper, no power
cycle, and screen only drops because the reset re-enumerates usb.

the BOOT0 jumper is off the board now (19 sep) - the probe is the only way in.
DFU is still in the chip, so if the probe or the header ever dies i refit the
jumper and it comes back.

## what the probe actually shows

three things printf cannot do:

  breakpoints        stop mid-loop and read every local
  live watches       read a variable while the cpu runs, no halt, no code change
  peripherals        read EXTI, GPIO, I2C registers by name, live

the EXTI check was the satisfying one. step 5 i proved the interrupt worked by
counting edges; now i can just read it:

  IMR    0x00000400    bit 10 unmasked, nothing else
  RTSR   0x00000400    rising edge only
  FTSR   0x00000000    no falling edge, or i would count twice
  PR     0x00000000    nothing pending, the handler keeps up

and the axis map, which took a whole bench session in step 2, in one breakpoint:

  raw.accel_y_g  -0.001708    ->  accel[1]  +0.001708
  raw.accel_z_g  -0.991250    ->  accel[2]  +0.991250
  raw.gyro_y_dps +0.455       ->  gyro[1]   -0.455

diag(+1,-1,-1), on both sensors, exactly. also caught raw.gyro_x_dps reading
0.385 five seconds after boot against the 0.6096 stored in the header - that is
step 2's thermal drift, cold vs warm, seen directly for the first time.

## debugger things that bit

live watches only work on file-scope or static symbols. int1_edges is static in
imu.c so it has a fixed address and works; att_reads is a local in main() and
lives on the stack, so there is no address to read and gdb says no symbol. for
locals use Threads & Variables at a breakpoint instead.

never put a conditional breakpoint on a hot path. gdb evaluates the condition by
halting, reading over swd, and resuming - every single hit. on a 105 Hz line the
target ends up running at a few percent of speed and the condition never comes
true. i sat there thinking it had not triggered. a plain breakpoint fires once,
which is all i wanted anyway.

only 6 breakpoints, and they are all hardware ones - software breakpoints work by
writing a trap instruction into the code, and the code is in flash.

after a breakpoint, ovr climbs and the next dtmax is huge. that is the halted cpu
not servicing USART1, and the real gap across the halt. both expected, neither
survives a power cycle.

no SWO pin on a 4-pin header, so no ITM printf and no SWO console. leave it
disabled in the profile.

## the first flash of the display and card block

16 sep. steps 6, 7 and 8 all went on the board in one session. the panel
works, the card works, the loop holds all of it at once. two things came out
different from what i had written here and both are corrected in place below:
the panel cannot be read at all, and the card is not the worst stall in the
loop - the usb console is.

## the display has no framebuffer

320 x 240 pixels at 2 bytes each is 150 KB. the chip has 128 KB of RAM. so
there is no picture in memory, ever.

instead gfx.c owns one band, 320 x 16 pixels, 10 KB. to repaint something the
screen says which rectangle changed, gfx cuts it into bands that fit the
buffer, and for each band asks the screen to draw itself into it, then sends
it to the panel. every primitive clips itself to the band, so drawing the
whole screen into a 16 row slice costs almost nothing outside the slice.

why one band per loop pass: the IMU sample gap is 9.5 ms and the loop has to
be back for the next sample. a band is 2 ms on the wire at 42 MBit/s, a whole
frame is 15 of them, so the display never holds the loop for more than 2 ms.
dirty rectangles keep it small anyway - a moving dot is two little squares,
two bands, and a number that did not change costs nothing.

## pixels on the wire

RGB565 - 5 bits red, 6 green, 5 blue, 16 bits a pixel. the panel wants the
high byte first and the M4 stores the low byte first, so every pixel is byte
swapped as it goes into the band; the buffer then goes out untouched.

18 bit would be 3 bytes a pixel for colours nobody can tell apart on a
2.8 inch panel. 16 it is.

## reading from the panel

writes run at 42 MBit/s. the datasheet says the write cycle is 100 ns
minimum, which is 10 MHz - so i am four times over, like every driver for
these modules. if pixels come out wrong the first thing to try is prescaler 4.

reads are another story: the read cycle is 150 ns minimum, 6.67 MHz. so every
read drops SPI1 to 5.25 MHz and puts it back after. at 42 MHz a read is just
rubbish.

the trap i wrote all this for: the 24 and 32 bit reads (04h, 09h, D3h) start
with one dummy clock, not a dummy byte. one dummy bit then 24 bits of ID, so
four bytes come back as 00 49 A0 FF and the ID is that shifted right by
seven. the 8 bit reads, 0Ah and 0Ch, have no dummy at all - p38 draws both
cases. lcd_probe prints the raw bytes and decodes the long one both ways.

the gate was two reads, not one. D3h for identity, and the pixel format
register before and after writing it, 06 then 05 - a write that goes in and
comes back proves the path without needing D3h, which the datasheet lets a
vendor blank out.

none of it works on this module. every read comes back FF - D3h, power mode,
pixel format, all four. not a blanked register; nothing drives the line at
all, and PA6 carries a pull-up so an undriven MISO reads exactly FF.

i checked the mcu side in the debugger before believing it. SPI1 CR1 344 -
master, mode 0, 8 bit, enabled; PA5 PA6 PA7 all AF5; CS high, DC and RST
where the driver left them. four clean transfers at 5.25 MHz, err 0, nothing
came back.

so the probe is advisory now. it still runs and still prints, because those
FFs are real evidence about this module, but lcd_init runs whatever it says
and its own read-back only happens where reads work. the colour bars are the
proof instead, and they came up first try.

the lesson: a read-back gate is worth having, but it must not be the thing
that decides whether to go on. writes and reads are separate paths and a
module can have one without the other.

## display init order

all from the datasheet:

  reset pin low 10 us or more, then 120 ms
  sleep out (11h), then 120 ms
  pixel format 55h
  madctl - orientation
  clear the whole frame memory to black
  display on (29h)
  backlight, last

the clear before display on matters: frame memory is random at power-on, and
with the backlight on that is a screen of static. so the panel stays dark
until a black frame is in it, then the boot screen goes up and the backlight
fades in over 300 ms.

## madctl

one register, six bits, says how memory maps onto the glass. MV swaps rows
and columns, that is landscape. MX and MY mirror. BGR swaps red and blue -
these panels are wired that way and need the bit set.

which combination is right is not in the datasheet, it depends on how the
glass is glued to the module. so the test pattern decides: five bars in the
order red green blue white grey, and a line of text. wrong order, flip BGR.
upside down, use the other constant. mirrored text, MX or MY.

settled: MV and BGR alone came out upside down, so it is MX MY MV BGR - E8.
BGR was right from the start; the bars read red green blue white grey first
try and the dot renders blue.

the bars are gone from the firmware now. they had one job, settling these
bits, and they did it once; boot is a black screen with the build date on it.

the orientation is not only cosmetic. the bottom of the screen is now the
usb-c edge, so the top is the edge opposite it, which is the front of the
car. screen.c moves the dot toward the top under braking, and braking throws
you forward, so the dot now points the way you are thrown. the other constant
pointed it backwards and looked perfectly fine.

## bitmap fonts

the panel cannot draw text, it only takes pixels. so a font is a table of
little pictures, one per character, 1 bit per pixel, packed in rows.

i did not draw them. tools/gen_fonts.py takes DejaVu Sans Bold - free to
embed - and rasterises it with FreeType through matplotlib, which the
python.org 3.12 python on this mac happens to have. three sizes, 12, 18 and
26 px cells. every glyph in a font has the same height and shares a baseline
so text lines up; widths are proportional. about 6.5 KB of flash.

one thing that bit: the lookup is code minus the first code, so a font's
characters must be one unbroken run. my first large font was 0-9 then . and
- and the dot vanished - it sits before 0 in ASCII. the generator asserts it
now.

and the consequence i forgot about later: the large font starts at character
45, so it holds - . and 0-9 and no letters at all. i wrote DASHBOARD in it
for the boot screen and got an empty screen. any text uses small or medium.

## the screen on the mac

gfx.c and screen.c have no HAL in them. tests/render_screen.c swaps the panel
for a framebuffer in RAM, renders the boot screen and screen 1 with made-up
numbers and writes them out as images. that is how the layout was checked
before a panel existed. it also counts bands: a full paint is 15, a dot move
plus a clock tick is 2, no change is 0.

## the screen, second pass

after looking at it on the balcony i took things off it. session number gone,
moving time gone, hdop and fix quality gone - none of them told me anything
while driving. what is left got more room:

  top       wall clock in local time, time since power-up, GPS and SD flags
  left      SPEED big, MAX, DIST
  centre    the gauge, unchanged
  right     temperature, humidity, pressure, gas
  bottom    satellites and position small, ALTITUDE on its own, bigger

two things i had to fix while moving it:

the left column dropped from four rows to three, which put MAX exactly level
with the gauge's left peak number - 132 and 0.6 rendered as 1320.6. the left
values now stop 10 px short of where the gauge numbers start.

the altitude on the panel was the raw GPS number. at hdop 2.2 that wanders by
tens of metres - i saw 114 m and 90 m at the same spot. it now shows the
fused one out of elevation.c, which is GPS steadied by the barometer, and it
sits still.

the live magnitude moved up by one line so its bottom is level with the top
of the side peak numbers. at rest the dot sits dead centre and the number was
landing on top of it.

## gps speed when nothing is moving

the panel said SPEED 2 and MAX 8 with the board sitting on a table. not a
bug in the maths - that is what the module reported.

speed noise tracks the fix. on the good balcony run, 9 satellites and hdop
1.2, it was 1.5-2 km/h. on the bad one, 6 satellites, hdop 2.5, no EGNOS, it
reached 8.

the real mistake was mine: only the odometer was gated, at 3 km/h. the
speedometer, the maximum and the acceleration estimate all read the raw
number, so 8 km/h of noise walked straight into vmax and - being over the
3 km/h gate - into the odometer too. 200 m of distance and 112 seconds of
moving time from a board that never moved.

now one floor, TRIP_SPEED_MIN_KMH, applied where the fix enters trip.c. below
it the speed is zero for everything downstream. 10 km/h for now, which is
above the worst noise i have seen; a real drive settles it.

the lesson: if a number is noisy, gate it once at the source. gating one
consumer and not the others is worse than not gating at all, because the
numbers stop agreeing with each other.
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

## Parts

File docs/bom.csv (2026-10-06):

Reference | Qty | Value | Manufacturer | MPN | Description | Footprint | Notes
BT1 | 1 | 3003 | Keystone Electronics | 3003 | Coin-cell holder, CR2032 / ML2032, THT | battery_holder:BAT_3003
C1 | 1 | 220u | Vishay | 593D227X9010E2TE3 | Tantalum capacitor 220uF 10V, E case, ESR 100 mOhm | supply_cap:220u_tantalum_cap | 5 V input bulk
C2,C13 | 2 | 4u7 | Samsung Electro-Mechanics | CL10A475KQ8NNNC | MLCC 4.7uF 6.3V X5R 10%, 0603 | Capacitor_SMD:C_0603_1608Metric
C3-C7,C10,C14-C17,C19-C22 | 14 | 100n | Samsung Electro-Mechanics | CL10B104KO8NNNC | MLCC 100nF 16V X7R 10%, 0603 | Capacitor_SMD:C_0603_1608Metric
C8 | 1 | 1u | Samsung Electro-Mechanics | CL10A105KP8NNNC | MLCC 1uF 10V X5R 10%, 0603 | Capacitor_SMD:C_0603_1608Metric
C9 | 1 | 10n | Samsung Electro-Mechanics | CL10B103KB8NNNC | MLCC 10nF 50V X7R 10%, 0603 | Capacitor_SMD:C_0603_1608Metric
C11,C12 | 2 | 15p | Samsung Electro-Mechanics | CL10C150JB8NNNC | MLCC 15pF 50V C0G 5%, 0603 | Capacitor_SMD:C_0603_1608Metric | crystal load
C18 | 1 | 10u | Samsung Electro-Mechanics | CL10A106MA8NRNC | MLCC 10uF 25V X5R 20%, 0603 | Capacitor_SMD:C_0603_1608Metric
D1 | 1 | PMEG3050EP | Nexperia | PMEG3050EP | Schottky diode 30V 5A, SOD-128 | supply_schottky:SMAF_L3.8-W2.5-LS4.7-RD | reverse-polarity protection
D3 | 1 | PMEG10020AELP | Nexperia | PMEG10020AELPX | Schottky diode 100V 2A, SOD-128 | charge_schottky:SMAF_L3.8-W2.5-LS4.7-RD | backup-cell charge path
J1,J2,J4-J6 | 5 | Conn_01x04 |  | CH31062V200 | Pin header 2.54 mm, 1x6, straight, THT | Connector_PinHeader_2.54mm:PinHeader_1x04_P2.54mm_Vertical | cut to 1x4
J3 | 1 | Conn_01x06 |  | CH31062V200 | Pin header 2.54 mm, 1x6, straight, THT | Connector_PinHeader_2.54mm:PinHeader_1x06_P2.54mm_Vertical
J7 | 1 | USB4930-00-A_REVA | GCT | USB4930-00-A | USB-C 2.0 receptacle, SMT, top mount | usb_c:GCT_USB4930-00-A_REVA
J8 | 1 | Conn_01x02 |  | CH31062V200 | Pin header 2.54 mm, 1x6, straight, THT | Connector_PinHeader_2.54mm:PinHeader_1x02_P2.54mm_Vertical | cut to 1x2; BOOT0 jumper, jumper removed
L1 | 1 | 39n |  | CCFH0603 C 39NJ - A80328017 | Inductor 39nH 5% 600mA, 0603 | Inductor_SMD:L_0603_1608Metric | VDDA filter; part number as listed by the supplier
LCD1 | 1 | MSP2807 |  | KMRTM28028-SPI | 2.8in 320x240 SPI TFT module, ILI9341, SD slot (lcdwiki MSP2807) | ili9341_display:ILI9341_display | plugs into female sockets, not soldered
R1 | 1 | 10k | Yageo | AC0603JR-0710KL | Resistor 10k 5%, 0603 | Resistor_SMD:R_0603_1608Metric
R2,R3 | 2 | 4k7 | Yageo | RC0603FR-074K7L | Resistor 4.7k 1%, 0603 | Resistor_SMD:R_0603_1608Metric | I2C pull-ups
R4,R5,R8 | 3 | 5k1 | Yageo | RC0603FR-075K1L | Resistor 5.1k 1%, 0603 | Resistor_SMD:R_0603_1608Metric
R6,R7 | 2 | 1k | Yageo | RC0603FR-071KL | Resistor 1k 1%, 0603 | Resistor_SMD:R_0603_1608Metric
TV1 | 1 | SMBJ5.0A |  | SMBJ5.0A | TVS diode 5V unidirectional 600W, SMB | tvs_diode:SMB_L4.6-W3.6-LS5.3-RD
U1 | 1 | MCP1825ST-3302E | Microchip | MCP1825ST-3302E/DB | LDO 3.3V 500mA, SOT-223 | Package_TO_SOT_SMD:SOT-223-3_TabPin2
U2 | 1 | LSM6DSOTR | STMicroelectronics | LSM6DSOTR | 6-axis IMU, LGA-14 | accelerometer_gyro:LGA-14_L3.0-W2.5-P0.50-TL | on the underside of the board
U3 | 1 | BME680 | Bosch Sensortec | BME680 | Gas, pressure, humidity and temperature sensor, LGA-8 | env_sensor:LGA-8_L3.0-W3.0-P0.80-TR
U4 | 1 | L76L-M33 | Quectel | L76L-M33 | GPS + GLONASS module | RF_GPS:Quectel_L76
U6 | 1 | GPS ANT-1 Chip |  | GPS ANT-1 Chip | GPS chip antenna 1575.42 MHz | gps_antenna:GPS_ANT-1_Chip_SMD | lifted ~1 cm above its pads, see README
U7 | 1 | STM32F446RCTx | STMicroelectronics | STM32F446RCT6 | MCU Cortex-M4F 180 MHz, 256 KB flash, LQFP-64 | Package_QFP:LQFP-64_10x10mm_P0.5mm
X1 | 1 | 12MHz | SJK | SJK-7U-12.000-18-30-80-C-30 | Crystal 12 MHz 18pF, 3.2x2.5 mm | Crystal:Crystal_SMD_Abracon_ABM8AIG-4Pin_3.2x2.5mm
LCD1 sockets | 2 |  |  |  | Female socket 2.54 mm, 1x14 and 1x4, THT |  | holds the display module; not in the schematic

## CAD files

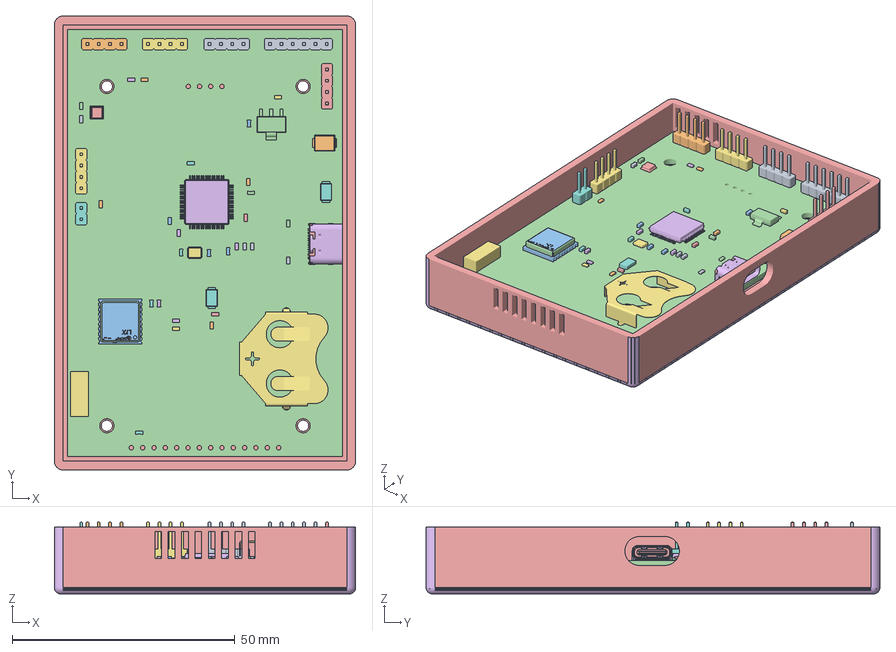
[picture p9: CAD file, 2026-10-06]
hardware/case/bottom_tray.FCStd
67.6 x 101.8 x 16.1 mm
L_0603_1608Metric
SMB_L4.6-W3.6-LS5.3-RD
L76L-M33
L76L-M001
L76L-M002
L76L-M003
L76L-M004
L76L-M005
L76L-M006
L76L-M007
L76L-M008
L76L-M009
L76L-M010
L76L-M011
L76L-M012
L76L-M013
L76L-M014
L76L-M015
L76L-M016
L76L-M017
L76L-M018
L76L-M019
L76L-M020
L76L-M021
L76L-M022
L76L-M023
L76L-M024
L76L-M025
L76L-M026
L76L-M027
L76L-M028
L76L-M029
L76L-M030
L76L-M031
L76L-M032
L76L-M033
L76L-M034
L76L-M035
L76L-M036
L76L-M037
L76L-M038
L76L-M039
L76L-M040
L76L-M041
C_0603_1608Metric
LQFP-64_10x10mm_P0.5mm
PinHeader_1x04_P254mm_Vertical
C_0603_1608Metric002
PinHeader_1x04_P254mm_Vertical001
R_0603_1608Metric
C_0603_1608Metric004
R_0603_1608Metric002
C_0603_1608Metric006
R_0603_1608Metric004
C_0603_1608Metric008
SMAF_L3.8-W2.5-LS4.7-RD
SMAF_L3.8-W2.5-LS4.7-RD001
SMAF_L3.8-W2.5-LS4.7-RD002
SMAF_L3.8-W2.5-LS4.7-RD003
SMAF_L3.8-W2.5-LS4.7-RD004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

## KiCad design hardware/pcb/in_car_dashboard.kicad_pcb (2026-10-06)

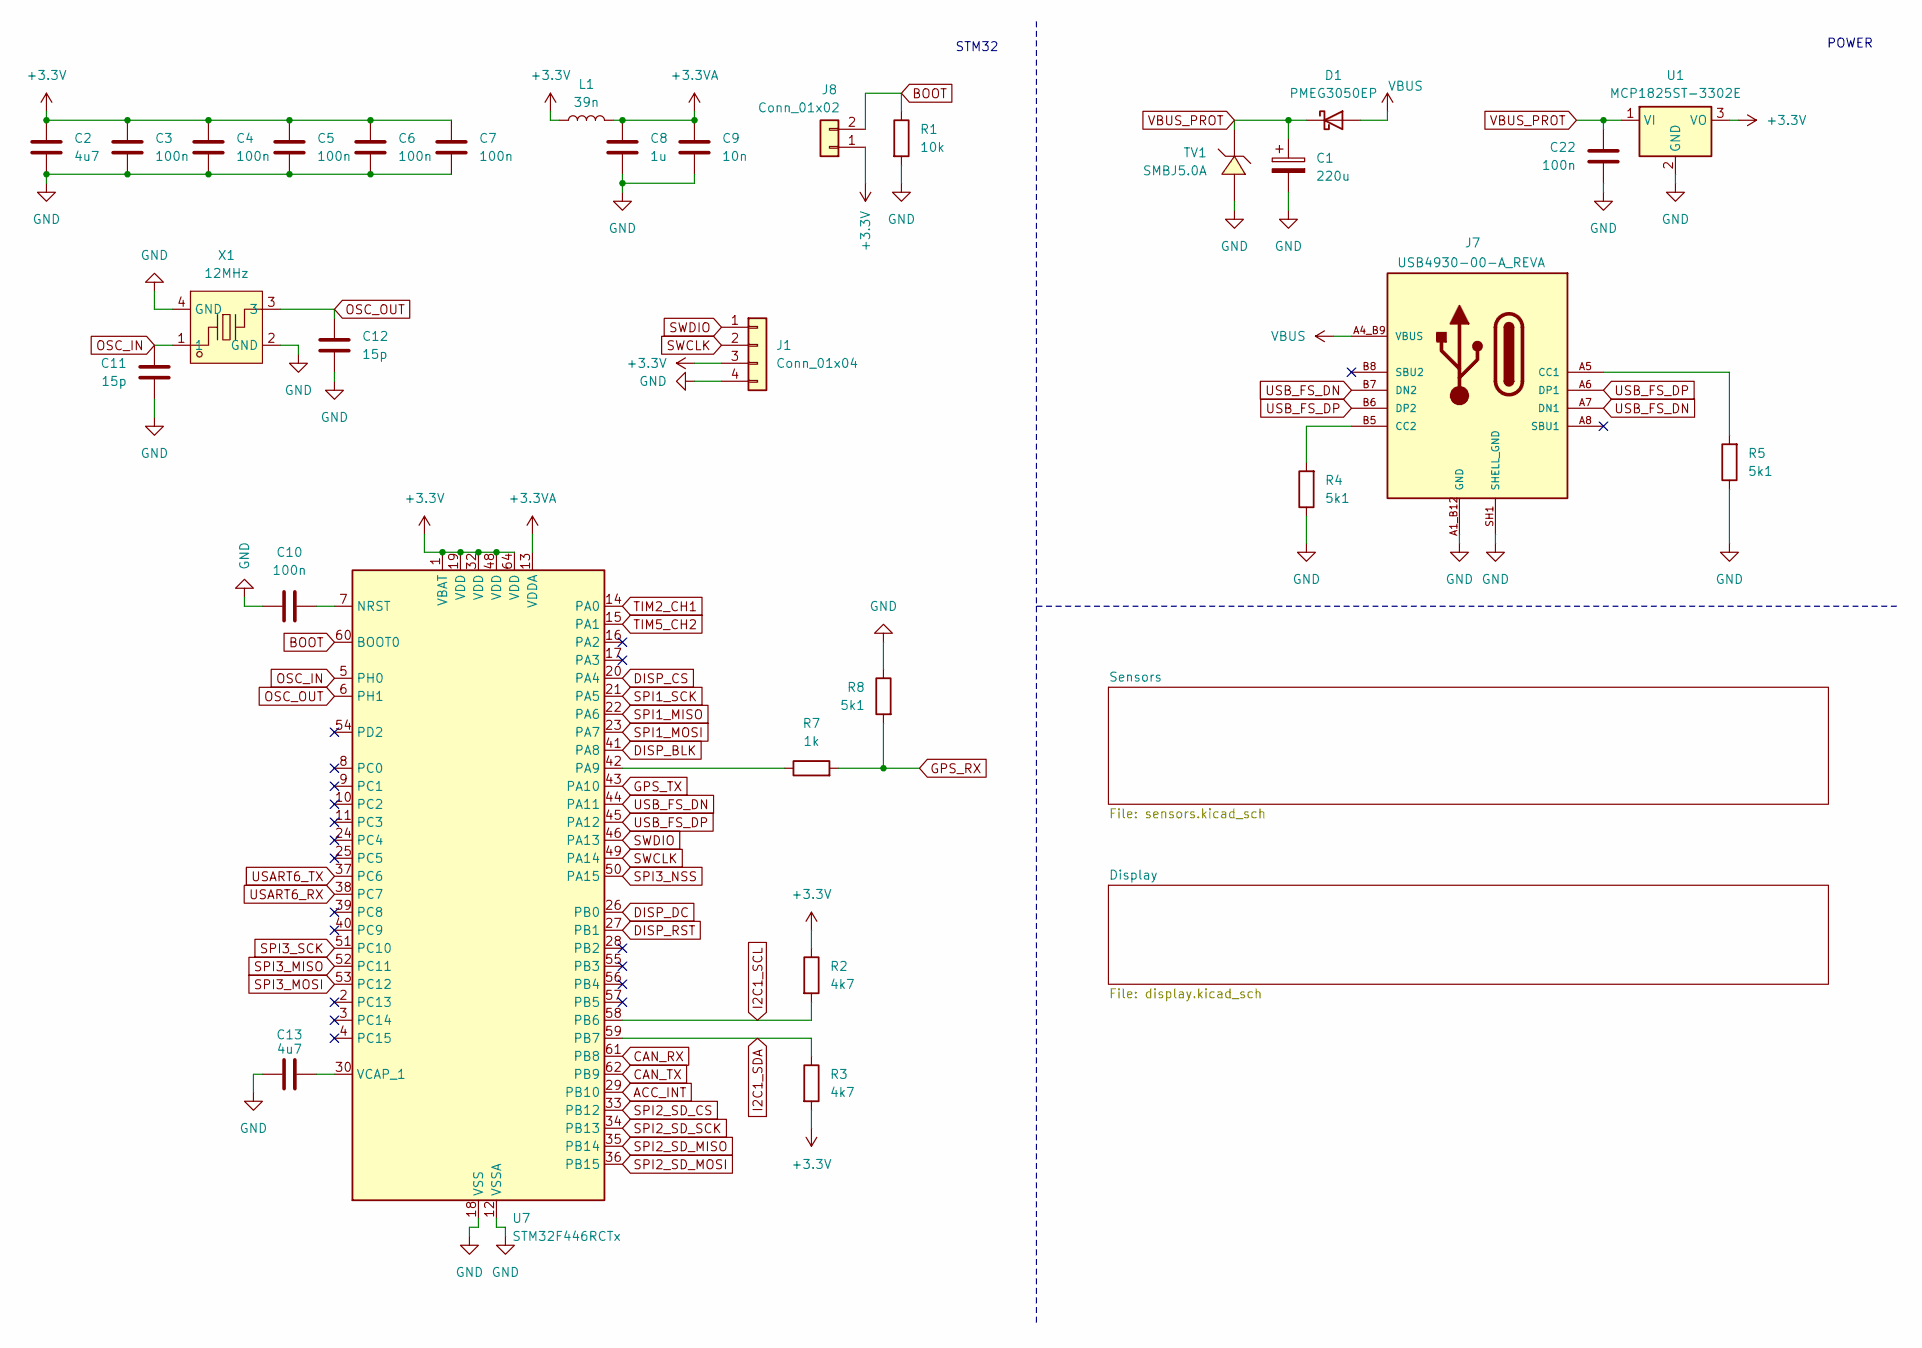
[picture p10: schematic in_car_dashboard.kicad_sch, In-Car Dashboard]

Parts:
C1: 220u; 220u_tantalum_cap
C2, C13: 4u7; C_0603_1608Metric
C3, C4, C5, C6, C7, C10, C22: 100n; C_0603_1608Metric
C8: 1u; C_0603_1608Metric
C9: 10n; C_0603_1608Metric
C11, C12: 15p; C_0603_1608Metric
D1: PMEG3050EP; SMAF_L3.8-W2.5-LS4.7-RD
J1: Conn_01x04; PinHeader_1x04_P2.54mm_Vertical
J7: USB4930-00-A_REVA; GCT_USB4930-00-A_REVA; PARTREV A
J8: Conn_01x02; PinHeader_1x02_P2.54mm_Vertical
L1: 39n; L_0603_1608Metric
R1: 10k; R_0603_1608Metric
R2, R3: 4k7; R_0603_1608Metric
R4, R5, R8: 5k1; R_0603_1608Metric
R7: 1k; R_0603_1608Metric
TV1: SMBJ5.0A; SMB_L4.6-W3.6-LS5.3-RD; MPN SMBJ5.0A-E3/52
U1: MCP1825ST-3302E; SOT-223-3_TabPin2; MPN MCP1825ST-3302E/DB
U7: STM32F446RCTx; LQFP-64_10x10mm_P0.5mm
X1: 12MHz; Crystal_SMD_Abracon_ABM8AIG-4Pin_3.2x2.5mm; MPN SJK-7U-12.000-18-30-80-C-30

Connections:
+3.3V: C2.1, C3.1, C4.1, C5.1, C6.1, C7.1, J1.3, J8.1, L1.1, R2.1, R3.2, U1.3 (VO), U7.1 (VBAT), U7.19 (VDD), U7.32 (VDD), U7.48 (VDD), U7.64 (VDD); also elsewhere on the board
+3.3VA: C8.1, C9.1, L1.2, U7.13 (VDDA)
ACC_INT: U7.29 (PB10); also elsewhere on the board
BOOT: J8.2, R1.1, U7.60 (BOOT0)
CAN_RX: U7.61 (PB8); also elsewhere on the board
CAN_TX: U7.62 (PB9); also elsewhere on the board
DISP_BLK: U7.41 (PA8); also elsewhere on the board
DISP_CS: U7.20 (PA4); also elsewhere on the board
DISP_DC: U7.26 (PB0); also elsewhere on the board
DISP_RST: U7.27 (PB1); also elsewhere on the board
GND: C1.2, C2.2, C3.2, C4.2, C5.2, C6.2, C7.2, C8.2, C9.2, C10.1, C11.1, C12.1, C13.2, C22.2, J1.4, J7.A1_B12 (GND), J7.B1_A12 (GND), J7.SH1 (SHELL_GND), J7.SH2 (SHELL_GND), J7.SH3 (SHELL_GND), J7.SH4 (SHELL_GND), R1.2, R4.1, R5.1, R8.1, TV1.2 (A), U1.2 (GND), U7.12 (VSSA), U7.18 (VSS), U7.31 (VSS), U7.47 (VSS), U7.63 (VSS), X1.2 (GND), X1.4 (GND); also elsewhere on the board
GPS_RX: R7.2, R8.2; also elsewhere on the board
GPS_TX: U7.43 (PA10); also elsewhere on the board
I2C1_SCL: R2.2, U7.58 (PB6); also elsewhere on the board
I2C1_SDA: R3.1, U7.59 (PB7); also elsewhere on the board
unnamed: J7.A5 (CC1), R5.2
unnamed: J7.B5 (CC2), R4.2
unnamed: C10.2, U7.7 (NRST)
unnamed: R7.1, U7.42 (PA9)
unnamed: C13.1, U7.30 (VCAP_1)
OSC_IN: C11.2, U7.5 (PH0), X1.1
OSC_OUT: C12.2, U7.6 (PH1), X1.3
SPI1_MISO: U7.22 (PA6); also elsewhere on the board
SPI1_MOSI: U7.23 (PA7); also elsewhere on the board
SPI1_SCK: U7.21 (PA5); also elsewhere on the board
SPI2_SD_CS: U7.33 (PB12); also elsewhere on the board
SPI2_SD_MISO: U7.35 (PB14); also elsewhere on the board
SPI2_SD_MOSI: U7.36 (PB15); also elsewhere on the board
SPI2_SD_SCK: U7.34 (PB13); also elsewhere on the board
SPI3_MISO: U7.52 (PC11); also elsewhere on the board
SPI3_MOSI: U7.53 (PC12); also elsewhere on the board
SPI3_NSS: U7.50 (PA15); also elsewhere on the board
SPI3_SCK: U7.51 (PC10); also elsewhere on the board
SWCLK: J1.2, U7.49 (PA14)
SWDIO: J1.1, U7.46 (PA13)
TIM2_CH1: U7.14 (PA0); also elsewhere on the board
TIM5_CH2: U7.15 (PA1); also elsewhere on the board
USART6_RX: U7.38 (PC7); also elsewhere on the board
USART6_TX: U7.37 (PC6); also elsewhere on the board
USB_FS_DN: J7.A7 (DN1), J7.B7 (DN2), U7.44 (PA11)
USB_FS_DP: J7.A6 (DP1), J7.B6 (DP2), U7.45 (PA12)
VBUS: D1.2 (A), J7.A4_B9 (VBUS), J7.B4_A9 (VBUS)
VBUS_PROT: C1.1, C22.1, D1.1 (K), TV1.1 (C), U1.1 (VI); also elsewhere on the board

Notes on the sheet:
STM32
POWER

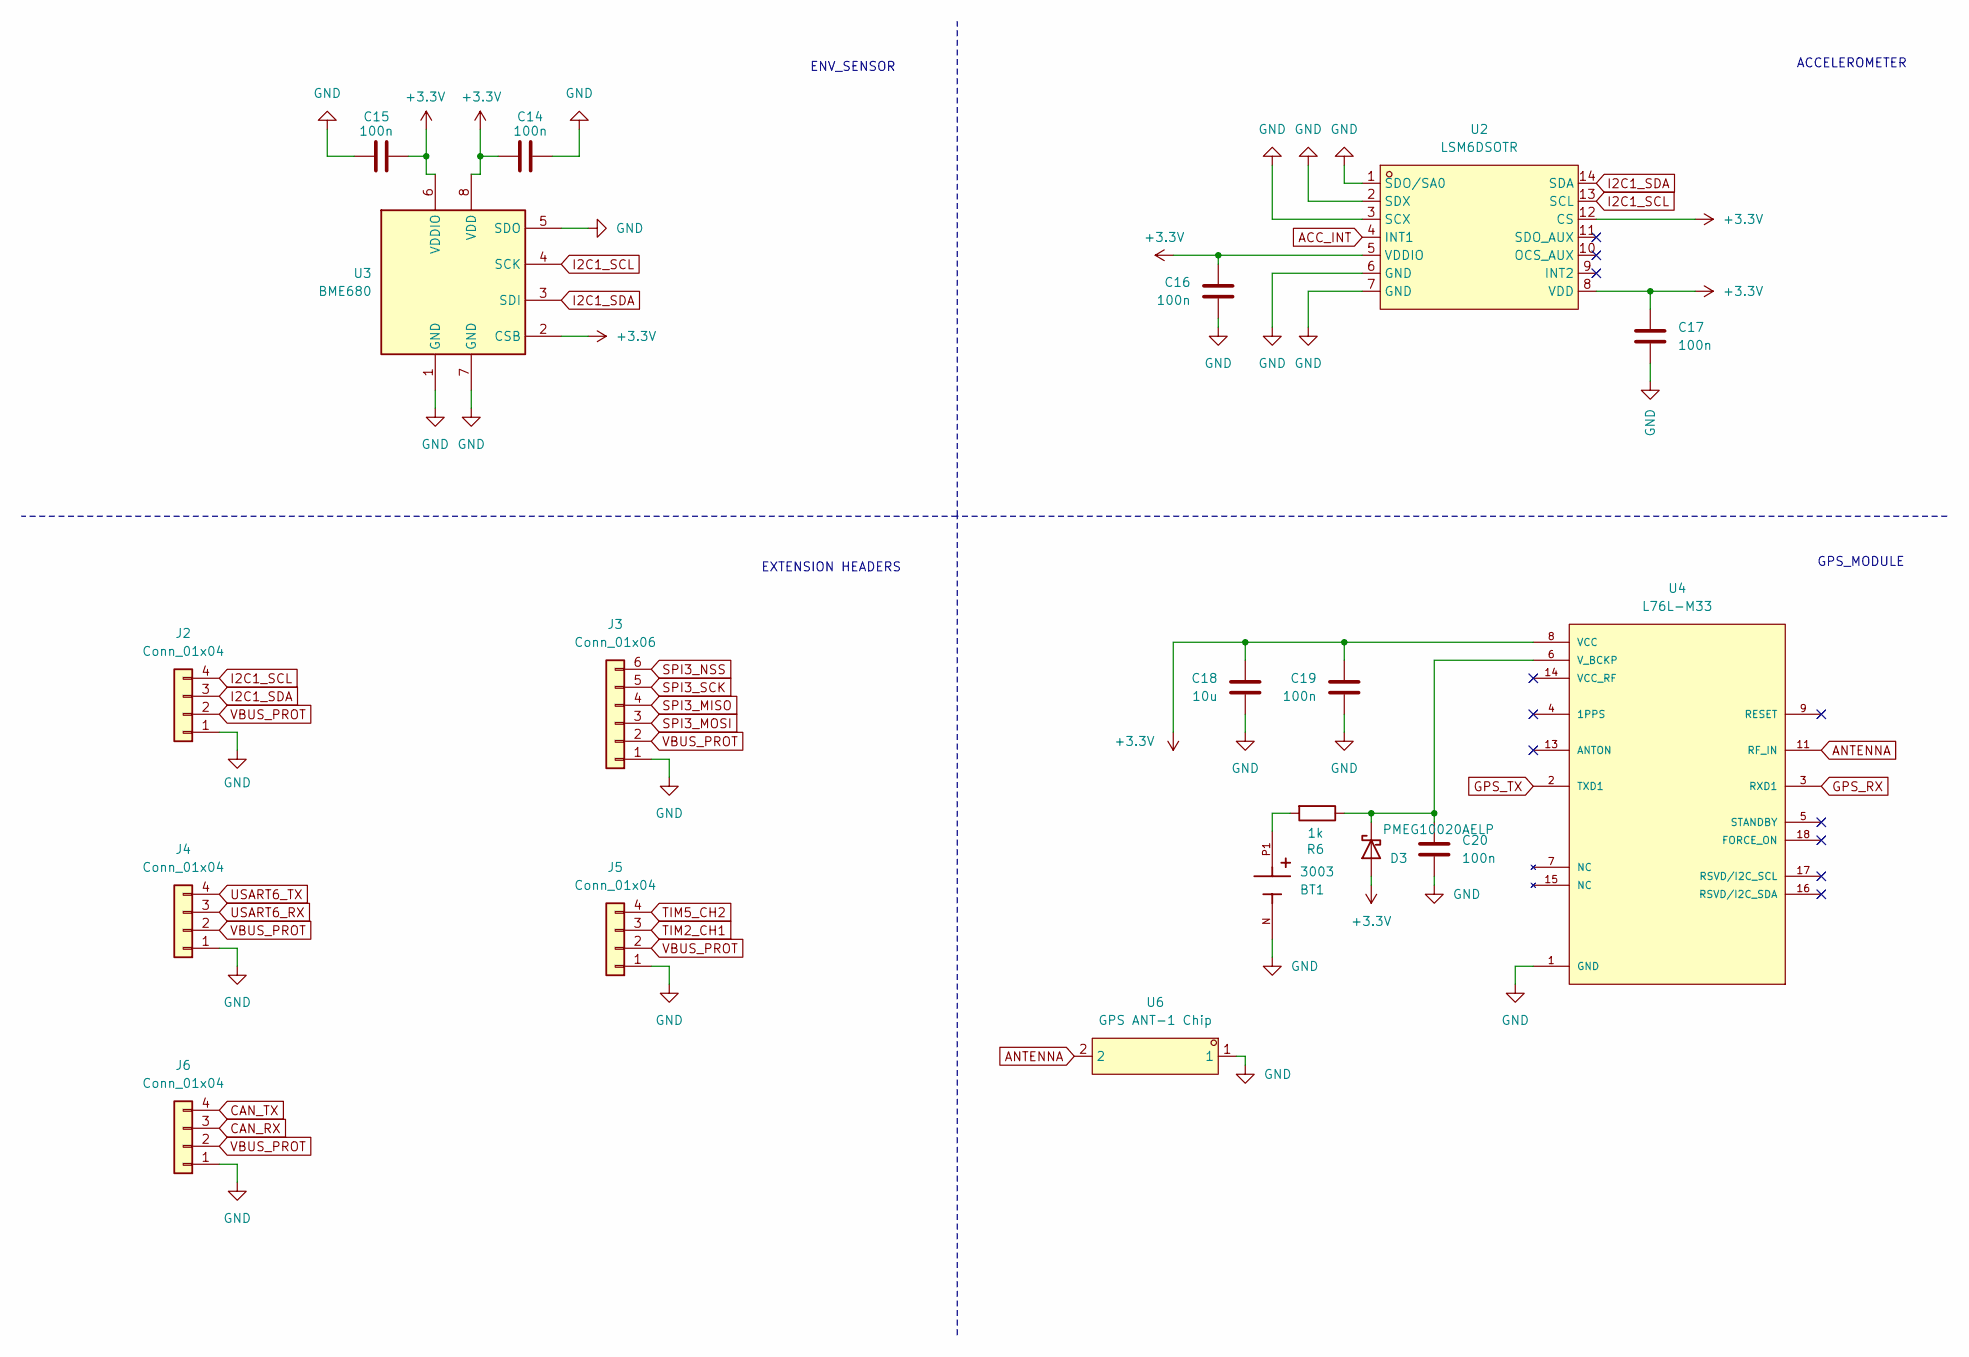
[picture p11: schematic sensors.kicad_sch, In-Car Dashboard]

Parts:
BT1: 3003; BAT_3003; PARTREV 5-JUN-09
C14, C15, C16, C17, C19, C20: 100n; C_0603_1608Metric
C18: 10u; C_0603_1608Metric
D3: PMEG10020AELP; SMAF_L3.8-W2.5-LS4.7-RD
J2, J4, J5, J6: Conn_01x04; PinHeader_1x04_P2.54mm_Vertical
J3: Conn_01x06; PinHeader_1x06_P2.54mm_Vertical
R6: 1k; R_0603_1608Metric
U2: LSM6DSOTR; LGA-14_L3.0-W2.5-P0.50-TL; MPN LSM6DSOTR; LCSC Part C2655100
U3: BME680; LGA-8_L3.0-W3.0-P0.80-TR
U4: L76L-M33; Quectel_L76
U6: GPS ANT-1 Chip; GPS_ANT-1_Chip_SMD; MPN GPS ANT-1 Chip

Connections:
+3.3V: C14.2, C15.2, C16.1, C17.1, C18.1, C19.1, D3.2 (A), U2.5 (VDDIO), U2.8 (VDD), U2.12 (CS), U3.2 (CSB), U3.6 (VDDIO), U3.8 (VDD), U4.8 (VCC); also elsewhere on the board
ACC_INT: U2.4 (INT1); also elsewhere on the board
ANTENNA: U4.11 (RF_IN), U6.2
CAN_RX: J6.3; also elsewhere on the board
CAN_TX: J6.4; also elsewhere on the board
GND: BT1.N, C14.1, C15.1, C16.2, C17.2, C18.2, C19.2, C20.2, J2.1, J3.1, J4.1, J5.1, J6.1, U2.1 (SDO/SA0), U2.2 (SDX), U2.3 (SCX), U2.6 (GND), U2.7 (GND), U3.1 (GND), U3.5 (SDO), U3.7 (GND), U4.1 (GND), U4.10 (GND), U4.12 (GND), U6.1; also elsewhere on the board
GPS_RX: U4.3 (RXD1); also elsewhere on the board
GPS_TX: U4.2 (TXD1); also elsewhere on the board
I2C1_SCL: J2.4, U2.13 (SCL), U3.4 (SCK); also elsewhere on the board
I2C1_SDA: J2.3, U2.14 (SDA), U3.3 (SDI); also elsewhere on the board
unnamed: BT1.P1, BT1.P2, R6.2
unnamed: C20.1, D3.1 (K), R6.1, U4.6 (V_BCKP)
SPI3_MISO: J3.4; also elsewhere on the board
SPI3_MOSI: J3.3; also elsewhere on the board
SPI3_NSS: J3.6; also elsewhere on the board
SPI3_SCK: J3.5; also elsewhere on the board
TIM2_CH1: J5.3; also elsewhere on the board
TIM5_CH2: J5.4; also elsewhere on the board
USART6_RX: J4.3; also elsewhere on the board
USART6_TX: J4.4; also elsewhere on the board
VBUS_PROT: J2.2, J3.2, J4.2, J5.2, J6.2; also elsewhere on the board

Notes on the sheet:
EXTENSION HEADERS
ENV_SENSOR
ACCELEROMETER
GPS_MODULE

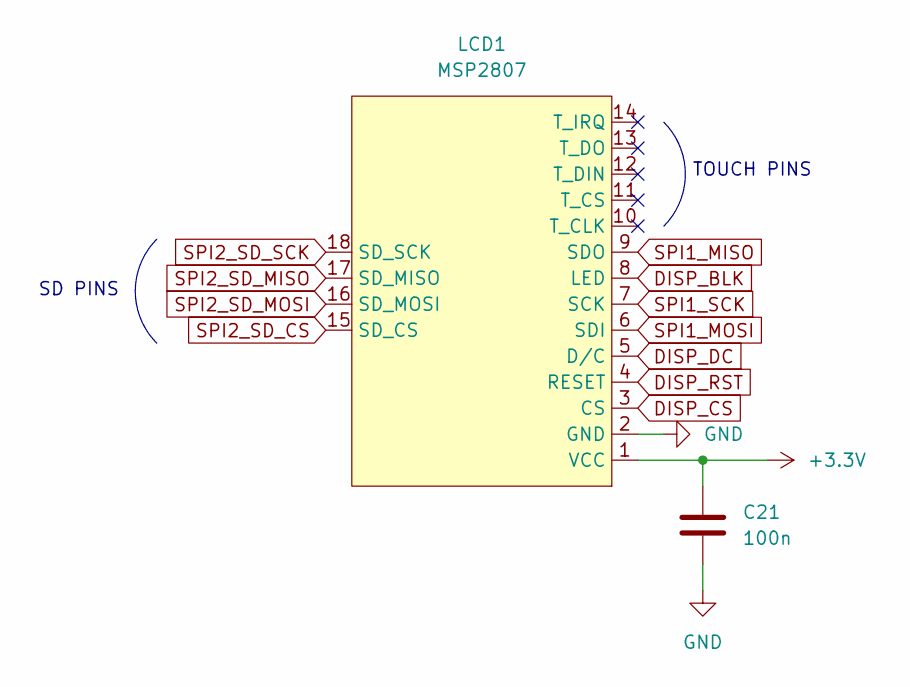
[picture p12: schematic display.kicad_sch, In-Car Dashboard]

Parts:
C21: 100n; C_0603_1608Metric
LCD1: MSP2807; ILI9341_display

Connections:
+3.3V: C21.2, LCD1.1 (VCC); also elsewhere on the board
DISP_BLK: LCD1.8 (LED); also elsewhere on the board
DISP_CS: LCD1.3 (CS); also elsewhere on the board
DISP_DC: LCD1.5 (D/C); also elsewhere on the board
DISP_RST: LCD1.4 (RESET); also elsewhere on the board
GND: C21.1, LCD1.2 (GND); also elsewhere on the board
SPI1_MISO: LCD1.9 (SDO); also elsewhere on the board
SPI1_MOSI: LCD1.6 (SDI); also elsewhere on the board
SPI1_SCK: LCD1.7 (SCK); also elsewhere on the board
SPI2_SD_CS: LCD1.15 (SD_CS); also elsewhere on the board
SPI2_SD_MISO: LCD1.17 (SD_MISO); also elsewhere on the board
SPI2_SD_MOSI: LCD1.16 (SD_MOSI); also elsewhere on the board
SPI2_SD_SCK: LCD1.18 (SD_SCK); also elsewhere on the board

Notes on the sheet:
TOUCH PINS
SD PINS

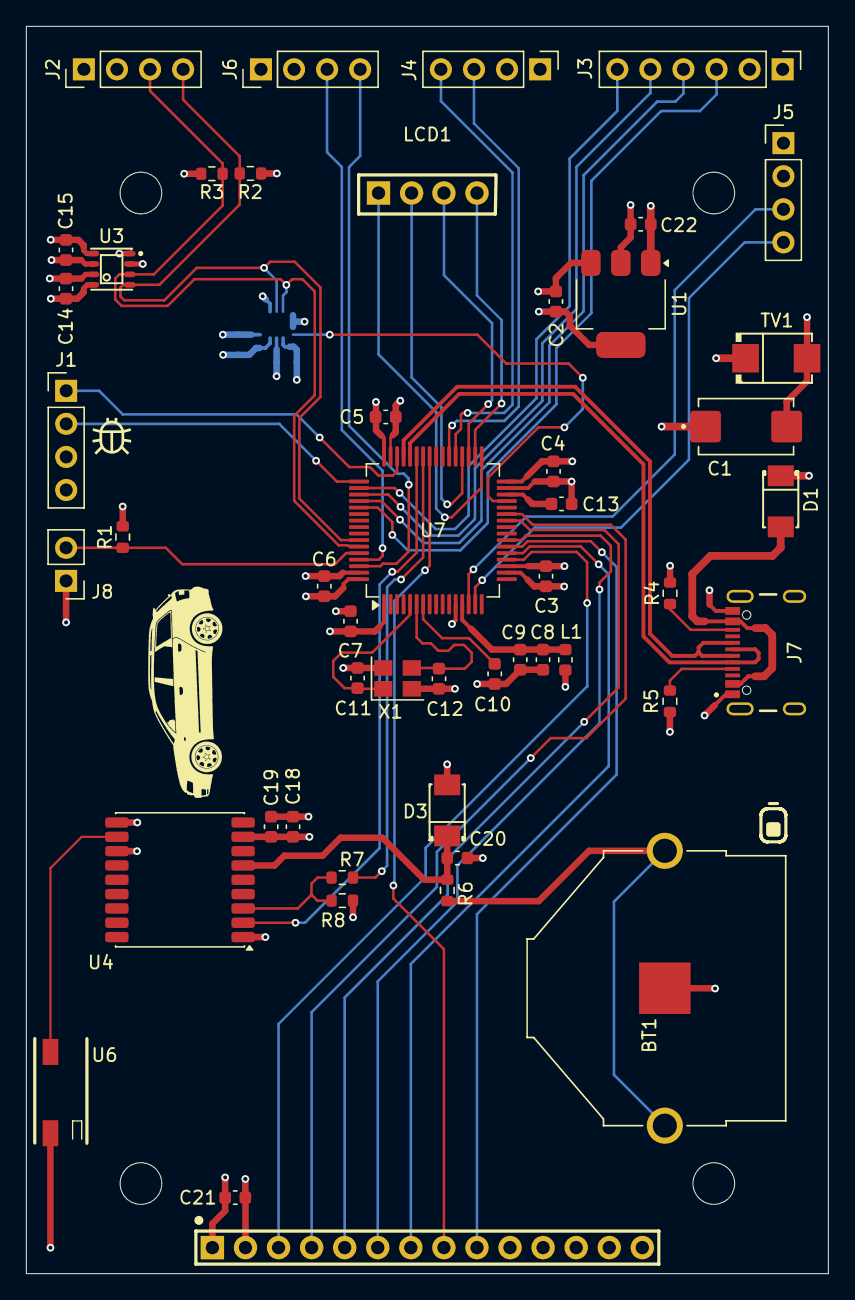
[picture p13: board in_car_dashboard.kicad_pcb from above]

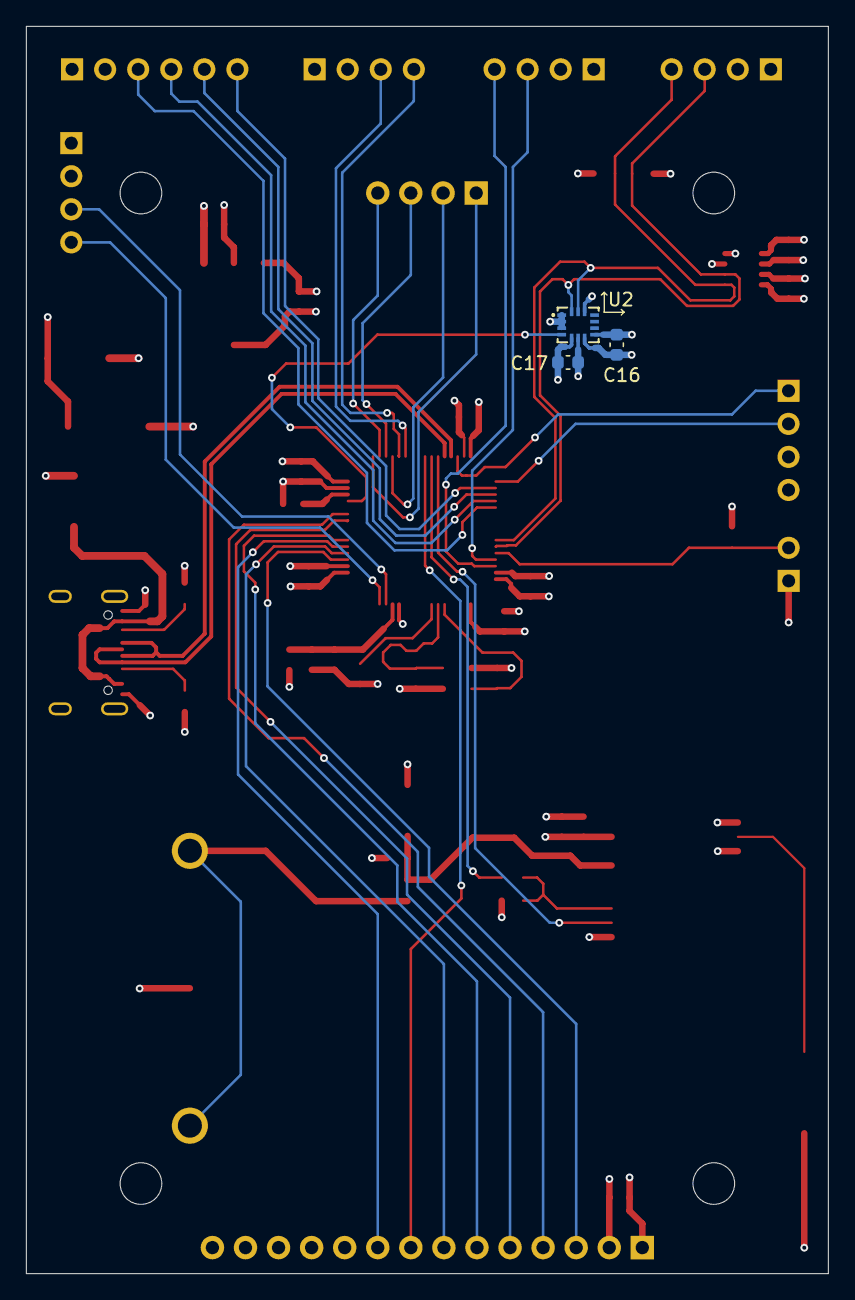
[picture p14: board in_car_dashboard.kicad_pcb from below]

Board: 4 copper layers, 61.6 x 95.8 mm, 51 parts (3 on the bottom side), 46 nets.

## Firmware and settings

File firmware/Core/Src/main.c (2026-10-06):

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
/* Includes ------------------------------------------------------------------*/
#include "main.h"
#include "can.h"
#include "fatfs.h"
#include "i2c.h"
#include "spi.h"
#include "tim.h"
#include "usart.h"
#include "usb_device.h"
#include "gpio.h"

/* USER CODE BEGIN Includes */
#include <stdio.h>
#include <string.h>
#include <math.h>
#include "usb_serial.h"
#include "uart_bus.h"
#include "sd_spi.h"
#include "imu.h"
#include "env.h"
#include "gps.h"
#include "vehicle_axes.h"
#include "attitude.h"
#include "trip.h"
#include "elevation.h"
#include "lcd.h"
#include "gfx.h"
#include "screen.h"
#include "session_log.h"
#include "session_record.h"
#include "console.h"
#include "bench_cal.h"

/* USER CODE END Includes */

/* USER CODE BEGIN PD */

// loop cadences, in ms. the IMU has no cadence of its own here - it runs on
// its data-ready interrupt, everything else is paced off HAL_GetTick
#define ENV_PERIOD_MS      3000u   // one BME680 measurement every 3 s
#define ENV_GIVE_UP_MS     1000u   // a measurement that never finishes is dropped after this
#define SCREEN_PERIOD_MS   50u     // the gauge dot at 20 Hz; the numbers change slower anyway
#define LOG_PERIOD_MS      10000u  // rewrite the session record every 10 s
#define LOG_RETRY_MS       5000u   // look for a card again every 5 s while there is none
#define CONSOLE_PERIOD_MS  1000u
#define BOOT_SCREEN_MS     2000u   // the boot screen stays up this long
#define USB_WAIT_MS        3000u   // how long boot waits for a terminal to attach
#define LCD_BRIGHTNESS     1000u   // permille; nothing to dim it from yet
#define SYSCLK_MHZ         168u    // DWT cycle counter -> microseconds

/* USER CODE END PD */


/* USER CODE BEGIN PV */

// file scope so the debugger can live-watch them; a local on the stack has no
// fixed address
static console_status_t st;      // init results and per-second counters
static screen_data_t    screen;  // what the panel is being shown
static session_record_t record;  // what the card is being sent
static bool display_ok;

/* USER CODE END PV */

void SystemClock_Config(void);
/* USER CODE BEGIN 0 */

// the DWT cycle counter: 168 counts per microsecond, free-running, the only
// clock fine enough to time one loop pass
static void dwt_init(void) {
    CoreDebug->DEMCR |= CoreDebug_DEMCR_TRCENA_Msk;
    DWT->CYCCNT = 0;
    DWT->CTRL |= DWT_CTRL_CYCCNTENA_Msk;
}

// one IMU sample: read, map into car axes, step the attitude filter, feed
// the trip stats. called once per INT1 edge, about 105 times a second
static void imu_tick(uint32_t dt_ms) {
    imu_sample_t raw;
    float sensor[3];
    float accel[3];
    float gyro[3];
    attitude_t att;

    if (imu_read(&raw) != IMU_OK) {
        st.att_err++;       // counted, not printed - a failing read at 104 Hz
        return;             // would bury the console
    }
    st.reads++;             // the read is also what drops INT1 again

    // sensor axes -> car axes; nothing above imu.c ever sees sensor axes
    sensor[0] = raw.accel_x_g;
    sensor[1] = raw.accel_y_g;
    sensor[2] = raw.accel_z_g;
    vehicle_map(sensor, accel);
    sensor[0] = raw.gyro_x_dps;
    sensor[1] = raw.gyro_y_dps;
    sensor[2] = raw.gyro_z_dps;
    vehicle_map(sensor, gyro);

    float dt_s = (float)dt_ms / 1000.0f;
    attitude_update(accel[0], accel[1], accel[2], gyro[0], gyro[1], gyro[2], dt_s);
    attitude_get(&att);
    trip_update_motion(accel, gyro, att.pitch_deg, att.roll_deg, dt_s);

    // tell the filter how hard the car is pushing, every sample - trip works
    // the sideways part out from speed x yaw rate 105 times a second. handed
    // over only once per GPS fix, a bend went up to 1 s uncorrected, which
    // read as ~9 deg of roll in session 17. used from the next sample on
    attitude_set_linear_accel(trip_long_accel_g(), trip_lat_accel_g());
}

// every counter a failure would have turned up in, collected once per record.
// the console shouts these at a terminal nobody is watching in the car; the
// card keeps them with the drive they belong to
static void gather_faults(session_faults_t *f) {
    gps_stats_t gst;
    sd_stats_t sd;
    log_stats_t log;

    memset(f, 0, sizeof(*f));
    gps_get_stats(&gst);
    sd_spi_get_stats(&sd);
    session_log_get_stats(&log);

    f->imu_init = st.imu_s;
    f->env_init = st.env_s;
    f->gps_init = st.gps_s;
    f->display_init = st.lcd_s;
    f->card_mounted = log.mounted;
    f->fatfs_error = log.fatfs_err;

    f->imu_read_errors = st.att_err;
    f->env_read_errors = st.env_err;
    f->gps_bad_checksums = gst.bad;
    f->gps_ring_overruns = uart_bus_overruns();
    f->display_errors = lcd_errors();
    f->card_crc_errors = sd.crc_errors;
    f->card_timeouts = sd.timeouts;
    f->card_rejected = sd.rejected;
    f->log_write_errors = log.errors;

    f->longest_imu_gap_ms = st.dt_max_session_ms;
    f->slowest_log_write_ms = log.max_write_ms;

    f->gps_date_refused_have = (gst.fix_no_date > 0u);
    f->gps_date_refused_empty = !gst.rejected_have;
    f->gps_date_refused_day = gst.rejected_day;
    f->gps_date_refused_month = gst.rejected_month;
    f->gps_date_refused_year = gst.rejected_year;
}

// everything the panel shows, pulled from the modules' getters
static void gather_screen(screen_data_t *d) {
    trip_stats_t t;
    gps_fix_t f;
    elevation_t e;

    trip_get(&t);
    gps_get_fix(&f);
    elev_get(&e);

    d->long_g = trip_push_long_g();
    d->lat_g = trip_push_lat_g();
    d->peak_accel_g = t.accel_peak_pos_g;
    // stored negative, shown as a size; fabsf and not a minus, because minus
    // zero prints as -0.0 on the panel
    d->peak_brake_g = fabsf(t.accel_peak_neg_g);
    d->peak_left_g = t.accel_peak_left_g;
    d->peak_right_g = fabsf(t.accel_peak_right_g);

    d->speed_kmh = trip_speed_kmh();
    d->speed_max_kmh = t.speed_max_kmh;
    d->distance_km = t.distance_km;
    d->coasting = t.coasting;

    d->env_valid = st.env_have;
    d->temp_c = st.env.temperature_c;
    d->hum_pct = st.env.humidity_pct;
    d->press_hpa = st.env.pressure_hpa;
    d->gas_valid = st.env.gas_valid;
    d->gas_kohm = st.env.gas_resistance_ohm / 1000.0f;

    d->duration_s = t.duration_s;
    d->sd_ok = session_log_ready();

    d->fix_valid = f.fix_valid;
    d->time_valid = f.time_valid;
    d->sats = f.sats_used;
    d->lat_deg = f.lat_deg;
    d->lon_deg = f.lon_deg;
    // the fused altitude, not the raw fix: GPS height wanders by tens of
    // metres on a poor fix and the barometer is what steadies it
    d->alt_m = e.valid ? e.altitude_m : f.altitude_m;
    d->alt_settled = e.valid && e.settled;
    d->hour = f.hour;
    d->minute = f.minute;
    d->second = f.second;
}

/* USER CODE END 0 */

/**
  * @brief  The application entry point.
  * @retval int
  */
int main(void)
{

  /* USER CODE BEGIN 1 */

    uint32_t last_att_tick = 0;      // HAL tick of the last IMU sample
    uint32_t att_last_edge = 0;      // last INT1 count this loop acted on
    uint32_t last_gps_tick = 0;      // updated_tick of the last fix handed to trip
    uint32_t env_last_start = 0;
    uint32_t env_ready_at = 0;
    uint32_t env_last_sample = 0;
    bool     env_pending = false;
    uint32_t last_screen = 0;
    uint32_t last_log = 0;
    uint32_t last_log_retry = 0;
    uint32_t last_console = 0;
    uint32_t boot_tick = 0;
    bool     boot_screen_up = false;

  /* USER CODE END 1 */

  /* MCU Configuration--------------------------------------------------------*/

  /* Reset of all peripherals, Initializes the Flash interface and the Systick. */
  HAL_Init();

  /* Configure the system clock */
  SystemClock_Config();

  /* Initialize all configured peripherals */
  MX_GPIO_Init();
  MX_CAN1_Init();
  MX_I2C1_Init();
  MX_SPI1_Init();
  MX_SPI2_Init();
  MX_SPI3_Init();
  MX_TIM1_Init();
  MX_TIM2_Init();
  MX_TIM5_Init();
  MX_USART1_UART_Init();
  MX_USART6_UART_Init();
  MX_USB_DEVICE_Init();
  MX_FATFS_Init();
  /* USER CODE BEGIN 2 */

    dwt_init();
    usb_serial_init();

    // the host needs a moment to enumerate the port and nothing printed
    // before that can arrive; wait for it, but not forever - the board still
    // has to run in the car with no host attached
    uint32_t wait = HAL_GetTick();
    while (!usb_serial_ready() && (HAL_GetTick() - wait) < USB_WAIT_MS) {
    }
    console_banner();
    console_i2c_scan();

    st.imu_s = imu_init();
    st.env_s = env_init();

    // hand the filter the two measured constants out of vehicle_axes.h; both
    // were recorded after vehicle_map, which is the frame attitude.c works in
    attitude_init();
    if (!attitude_set_mount(VEHICLE_REST_ACCEL_X, VEHICLE_REST_ACCEL_Y, VEHICLE_REST_ACCEL_Z)) {
        printf("attitude: mount vector too short, staying level\n");
    }
    attitude_set_gyro_bias(VEHICLE_GYRO_BIAS_X, VEHICLE_GYRO_BIAS_Y, VEHICLE_GYRO_BIAS_Z);
    // hand the sensor its own interrupt line; from here the loop is paced by
    // the LSM6DSO and not by a timer
    if (st.imu_s == IMU_OK) {
        st.int1_s = imu_int1_enable();
    }
    trip_init();
    elev_init();

    // the display: the ID gate first, then the full init, then the colour
    // bars while the backlight fades up. the gate is advisory - this module
    // never drives SDO, so every read answers FF; the numbers still go on the
    // console and the colour bars are what proves the write path
    (void)lcd_probe(&st.lcd_probe);
    st.lcd_s = lcd_init();
    display_ok = (st.lcd_s == LCD_OK);
    gfx_init(screen_paint, lcd_write_band);
    screen_init();
    if (display_ok) {
        screen_show_boot();
        while (gfx_flush_band()) {
        }
        lcd_backlight_set(LCD_BRIGHTNESS);
        boot_screen_up = true;
    }

    // the card: mount, open the file, claim this drive's record. no card
    // detect pin, so a missing card is just a failed init, retried in the loop
    st.log_s = session_log_init();

    // starts the USART1 receive interrupt; the module has been talking since
    // power-up, from here on its bytes land in the ring instead of being lost.
    // last on purpose: the panel init and the card mount above stall for well
    // over the ~265 ms the old 256-byte ring lasted at 9600 baud, which lost bytes
    // on every boot and hid the real stalls in gps_ring_overruns
    st.gps_s = gps_init();

    console_report_init(&st);

    // start the clocks here; left at zero the first dt would be the whole USB
    // wait above, which prints as a startling dtmax on the first line
    boot_tick = HAL_GetTick();
    last_att_tick = boot_tick;
    last_console = boot_tick;
    last_log = boot_tick;
    last_log_retry = boot_tick;
    env_last_start = boot_tick - ENV_PERIOD_MS;   // first measurement straight away

  /* USER CODE END 2 */

  /* Infinite loop */
  /* USER CODE BEGIN WHILE */
  while (1)
  {
    /* USER CODE END WHILE */

    /* USER CODE BEGIN 3 */
      uint32_t pass_start = DWT->CYCCNT;
      uint32_t now = HAL_GetTick();

      // drain the ring every pass - the module sends up to ~900 bytes a second
      // and the ring holds 2048, ~2 s; a slow card write is the worst wait
      if (st.gps_s == GPS_OK) {
          gps_poll();
      }

      // attitude tick - one filter step per INT1 edge, about 105 a second. the
      // count only ever goes up in the ISR, so reading it here cannot race
      uint32_t att_edge = imu_int1_count();
      if ((st.imu_s == IMU_OK) && (att_edge != att_last_edge)) {
          uint32_t dt_ms = now - last_att_tick;
          att_last_edge = att_edge;
          last_att_tick = now;
          if (dt_ms > st.dt_max_ms) {
              st.dt_max_ms = dt_ms;
          }
          if (dt_ms > st.dt_max_session_ms) {
              st.dt_max_session_ms = dt_ms;     // goes in the record's faults
          }
          imu_tick(dt_ms);
      }

      // a fresh RMC: hand it to the trip stats once. once only - every call
      // restarts trip's between-fixes clock
      if (st.gps_s == GPS_OK) {
          gps_fix_t fix;
          gps_get_fix(&fix);
          if (fix.updated_tick != last_gps_tick) {
              last_gps_tick = fix.updated_tick;
              trip_update_gps(&fix);
          }
      }

      // the BME680, in two halves so the loop never waits on it: trigger,
      // come back ~143 ms later for the result
      if (st.env_s == ENV_OK) {
          if (!env_pending) {
              if ((now - env_last_start) >= ENV_PERIOD_MS) {
                  uint32_t wait_ms;
                  env_last_start = now;
                  if (env_start(&wait_ms) == ENV_OK) {
                      env_pending = true;
                      env_ready_at = now + wait_ms;
                  } else {
                      st.env_err++;
                  }
              }
          } else if ((int32_t)(now - env_ready_at) >= 0) {
              env_status_t s = env_read(&st.env);
              if (s == ENV_OK) {
                  env_pending = false;
                  gps_fix_t fix;
                  gps_get_fix(&fix);
                  float dt_s = st.env_have ? (float)(now - env_last_sample) / 1000.0f
                                           : (float)ENV_PERIOD_MS / 1000.0f;
                  env_last_sample = now;
                  st.env_have = true;
                  trip_update_env(st.env.temperature_c, st.env.pressure_hpa, st.env.humidity_pct);
                  elev_update(st.env.pressure_hpa, fix.fix_valid, fix.altitude_m, dt_s);
              } else if (s == ENV_ERR_NO_DATA) {
                  env_ready_at = now + 5u;                  // not done yet, look again soon
                  if ((now - env_last_start) > ENV_GIVE_UP_MS) {
                      env_pending = false;                 // stuck; the next period retriggers
                      st.env_err++;
                  }
              } else {
                  env_pending = false;                     // bus error; try again next period
                  st.env_err++;
              }
          }
      }

      // the panel: the boot screen gives way to the drive view, then one band
      // per pass at most - a full frame is 15 bands, a dot move is 2
      if (display_ok) {
          if (boot_screen_up && ((now - boot_tick) >= BOOT_SCREEN_MS)) {
              boot_screen_up = false;
              screen_show_main();
          }
          if (!boot_screen_up && ((now - last_screen) >= SCREEN_PERIOD_MS)) {
              last_screen = now;
              gather_screen(&screen);
              screen_update(&screen);
          }
          gfx_flush_band();
          lcd_backlight_tick();
      }

      // the card: rewrite this drive's record every 10 s, or keep looking for
      // a card every 5 s until one turns up
      if (session_log_ready()) {
          if ((now - last_log) >= LOG_PERIOD_MS) {
              trip_stats_t t;
              elevation_t e;
              session_faults_t faults;
              last_log = now;
              trip_get(&t);
              elev_get(&e);
              gather_faults(&faults);
              session_record_build(&record, session_log_session_n(), &t, &e, &faults);
              st.log_s = session_log_write(&record);
          }
      } else if ((now - last_log_retry) >= LOG_RETRY_MS) {
          last_log_retry = now;
          st.log_s = session_log_init();
          last_log = now;
      }

      // the console, once a second, and the per-second maxima start over
      if ((now - last_console) >= CONSOLE_PERIOD_MS) {
          last_console = now;
          console_report(&st);
          st.dt_max_ms = 0;
          st.pass_max_us = 0;
          st.pass_count = 0;
      }

      bench_cal_tick(st.imu_s == IMU_OK);

      // how long this pass took; the budget is the ~9.5 ms between IMU samples
      uint32_t pass_us = (DWT->CYCCNT - pass_start) / SYSCLK_MHZ;
      if (pass_us > st.pass_max_us) {
          st.pass_max_us = pass_us;
      }
      st.pass_count++;
  }

  /* USER CODE END 3 */
}

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


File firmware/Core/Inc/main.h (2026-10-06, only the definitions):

#define OSC_IN_Pin GPIO_PIN_0
#define OSC_IN_GPIO_Port GPIOH
#define OSC_OUT_Pin GPIO_PIN_1
#define OSC_OUT_GPIO_Port GPIOH
#define EXP_TIM2_CH1_Pin GPIO_PIN_0
#define EXP_TIM2_CH1_GPIO_Port GPIOA
#define EXP_TIM5_CH2_Pin GPIO_PIN_1
#define EXP_TIM5_CH2_GPIO_Port GPIOA
#define LCD_CS_Pin GPIO_PIN_4
#define LCD_CS_GPIO_Port GPIOA
#define LCD_SCK_Pin GPIO_PIN_5
#define LCD_SCK_GPIO_Port GPIOA
#define LCD_MISO_Pin GPIO_PIN_6
#define LCD_MISO_GPIO_Port GPIOA
#define LCD_MOSI_Pin GPIO_PIN_7
#define LCD_MOSI_GPIO_Port GPIOA
#define LCD_DC_Pin GPIO_PIN_0
#define LCD_DC_GPIO_Port GPIOB
#define LCD_RST_Pin GPIO_PIN_1
#define LCD_RST_GPIO_Port GPIOB
#define ACC_INT_Pin GPIO_PIN_10
#define ACC_INT_GPIO_Port GPIOB
#define ACC_INT_EXTI_IRQn EXTI15_10_IRQn
#define SD_CS_Pin GPIO_PIN_12
#define SD_CS_GPIO_Port GPIOB
#define SD_SCK_Pin GPIO_PIN_13
#define SD_SCK_GPIO_Port GPIOB
#define SD_MISO_Pin GPIO_PIN_14
#define SD_MISO_GPIO_Port GPIOB
#define SD_MOSI_Pin GPIO_PIN_15
#define SD_MOSI_GPIO_Port GPIOB
#define EXP_UART_TX_Pin GPIO_PIN_6
#define EXP_UART_TX_GPIO_Port GPIOC
#define EXP_UART_RX_Pin GPIO_PIN_7
#define EXP_UART_RX_GPIO_Port GPIOC
#define LCD_BL_PWM_Pin GPIO_PIN_8
#define LCD_BL_PWM_GPIO_Port GPIOA
#define GPS_RX_Pin GPIO_PIN_9
#define GPS_RX_GPIO_Port GPIOA
#define GPS_TX_Pin GPIO_PIN_10
#define GPS_TX_GPIO_Port GPIOA
#define USB_DM_Pin GPIO_PIN_11
#define USB_DM_GPIO_Port GPIOA
#define USB_DP_Pin GPIO_PIN_12
#define USB_DP_GPIO_Port GPIOA
#define SWDIO_Pin GPIO_PIN_13
#define SWDIO_GPIO_Port GPIOA
#define SWCLK_Pin GPIO_PIN_14
#define SWCLK_GPIO_Port GPIOA
#define EXP_SPI3_CS_Pin GPIO_PIN_15
#define EXP_SPI3_CS_GPIO_Port GPIOA
#define EXP_SPI3_SCK_Pin GPIO_PIN_10
#define EXP_SPI3_SCK_GPIO_Port GPIOC
#define EXP_SPI3_MISO_Pin GPIO_PIN_11
#define EXP_SPI3_MISO_GPIO_Port GPIOC
#define EXP_SPI3_MOSI_Pin GPIO_PIN_12
#define EXP_SPI3_MOSI_GPIO_Port GPIOC

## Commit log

2026-10-06 In-car dashboard: firmware, KiCad board, case and docs
    - STM32F446 firmware with host tests (243 checks)
    - KiCad 10 project in_car_dashboard, rev A, with its custom libraries
    (symbols and footprints; 3D models not included)
    - FreeCAD bottom tray
    - BOM with manufacturer part numbers, schematic and board pictures
    - notes, the car's numbers and the case design note
    [bom.csv, bottom_tray.FCStd, display.kicad_sch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]
2026-10-06 README: new renders, schematic pictures, case photo and display mounting
2026-10-13 Firmware: car-axis vectors for trip, 5 Hz GPS at 115200, 3-digit speed
    - trip was handed the board's own axes (vehicle_map only) while the mount
    rotation lived inside attitude.c. At the 43.4 deg dash mount that left
    0.69 g of gravity on the forward axis, so braking never registered and
    the yaw rate behind the lateral correction read 27% short.
    attitude_get_car_axes() now gives trip the rotated, bias-free sample.
    - GPS switched at boot to 115200 baud and 5 Hz (PMTK251, PMTK314, PMTK220)
    with a 9600 / 1 Hz fallback. uart_bus gains TX and a runtime baud change;
    nmea builds PMTK commands and parses PMTK001. trip's GPS forward push is
    the speed change over ~1 s instead of fix to fix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
2026-10-13 Case: lid and spacer tubes, STEP exports, docs brought up to date
    - top_case.FCStd and spacer_tube.FCStd: the lid (display window, SD notch,
    four posts, countersunk screw holes) and the spacer tube, modelled and
    geometry-checked, not printed yet.
    - bottom_tray.FCStd tidied; it keeps the imported board model as the
    reference every case dimension is taken from.
    - One set of four countersunk self-tapping screws clamps lid, display,
    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
2026-10-15 Firmware: restructure App/ into one lowercase folder per subsystem (sensors, gps, fusion, display, storage, console, drivers, fonts) before FreeRTOS, with CMake paths, test compile lines, font script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
2026-10-15 Firmware: superloop moved onto FreeRTOS with eight tasks, IMU highest and SD logger lowest, plus a per-task watchdog, so card writes no longer cost IMU samples; README and notes updated.
2026-10-15 Firmware: Bosch BSEC air quality (IAQ, eCO2, breath VOC) with a 4 °C heat offset, its state saved to BSEC.BIN, IAQ coloured on the panel, BSEC optional and gitignored; README, notes and vehicle info 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
2026-10-24 Winter clock offset, a tidier gauge on the panel (ring moved up, smaller live g number on the ring, -- for speed before a fix), the case render and DFU flashing in the README, and docs brought up to 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

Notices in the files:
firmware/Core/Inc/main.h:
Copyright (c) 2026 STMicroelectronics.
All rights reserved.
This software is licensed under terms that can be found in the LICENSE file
